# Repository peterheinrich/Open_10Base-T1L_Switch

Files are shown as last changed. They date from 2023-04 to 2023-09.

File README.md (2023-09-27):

# !!! UNTESTED DESIGN STUDY - WORK IN PROGRESS !!!

# Open_10Base-T1L_Switch
Open Hardware 7-Port 10Base-T1L and 1-Port 20/100/1000Base-T Field Switch Design

Schematic: [Open_10Base-T1L_Switch-sch.pdf](Open_10Base-T1L_Switch-sch.pdf)

## Architecture ##
Two 5-port switch ICs (SJA1105Q) form the basis of the design. Daisy chaining the two ICs gives a total of 8 ports.
Seven of these ports are attachted to 10Base-T1L PHYs (ADIN1100), while one port is attached to a 1000Base-T PHY (KSZ9131) as uplink. 

Each of the 10Base-T1L ports offer power over datalines utilizing two 5-Port power management controllers (LTC4296) with SCC support for power delivery negotiation. The design is 24V only and supports PoDL Class 12.

An RP2040 functions as a system controller configuring the switch components.

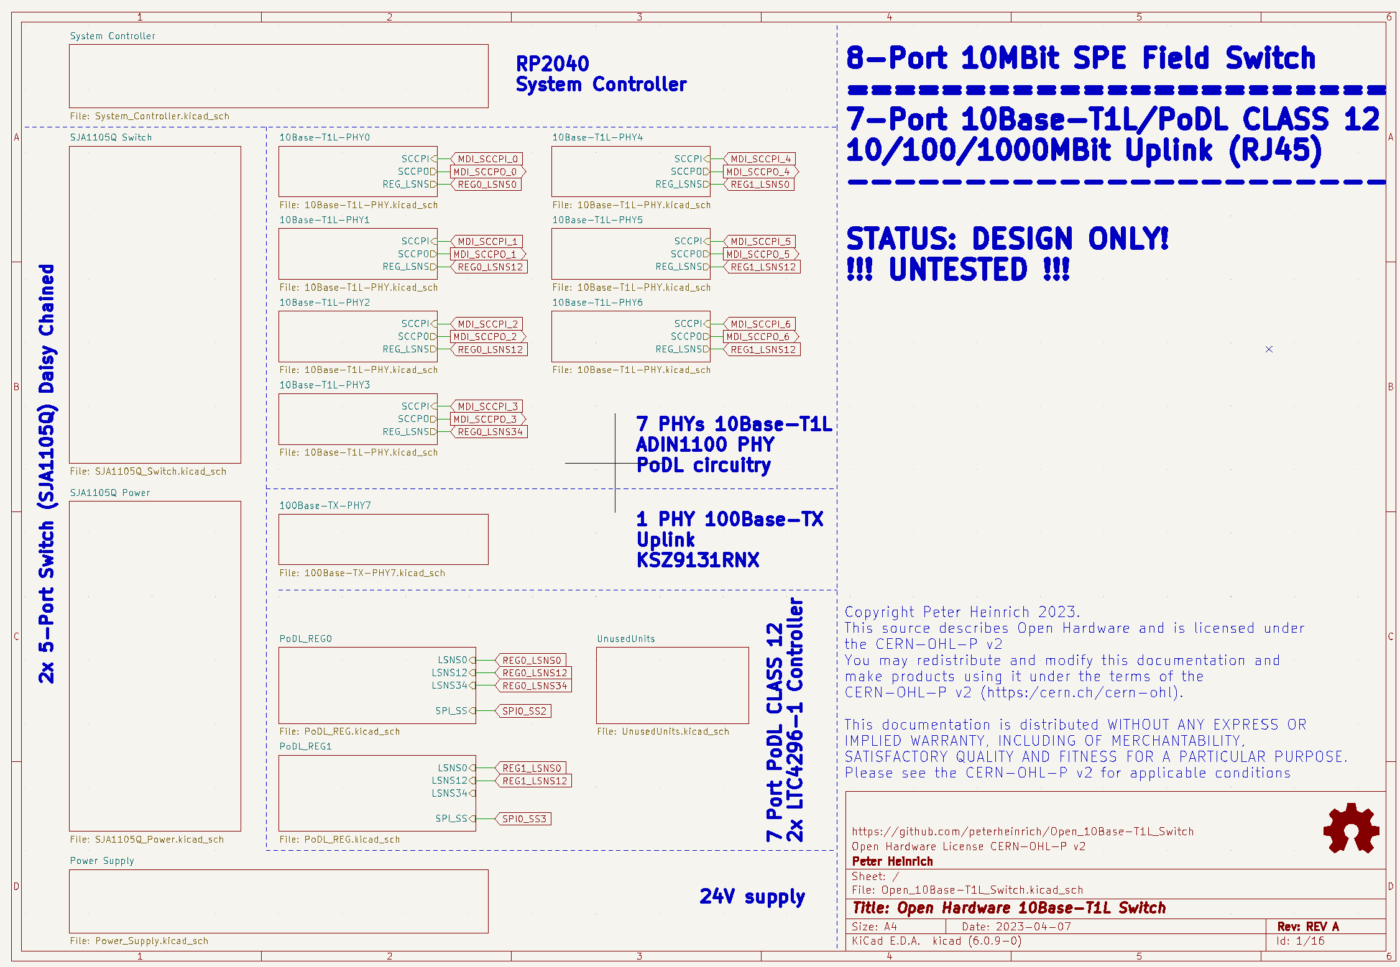
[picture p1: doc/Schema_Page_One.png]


## Current Placement ##
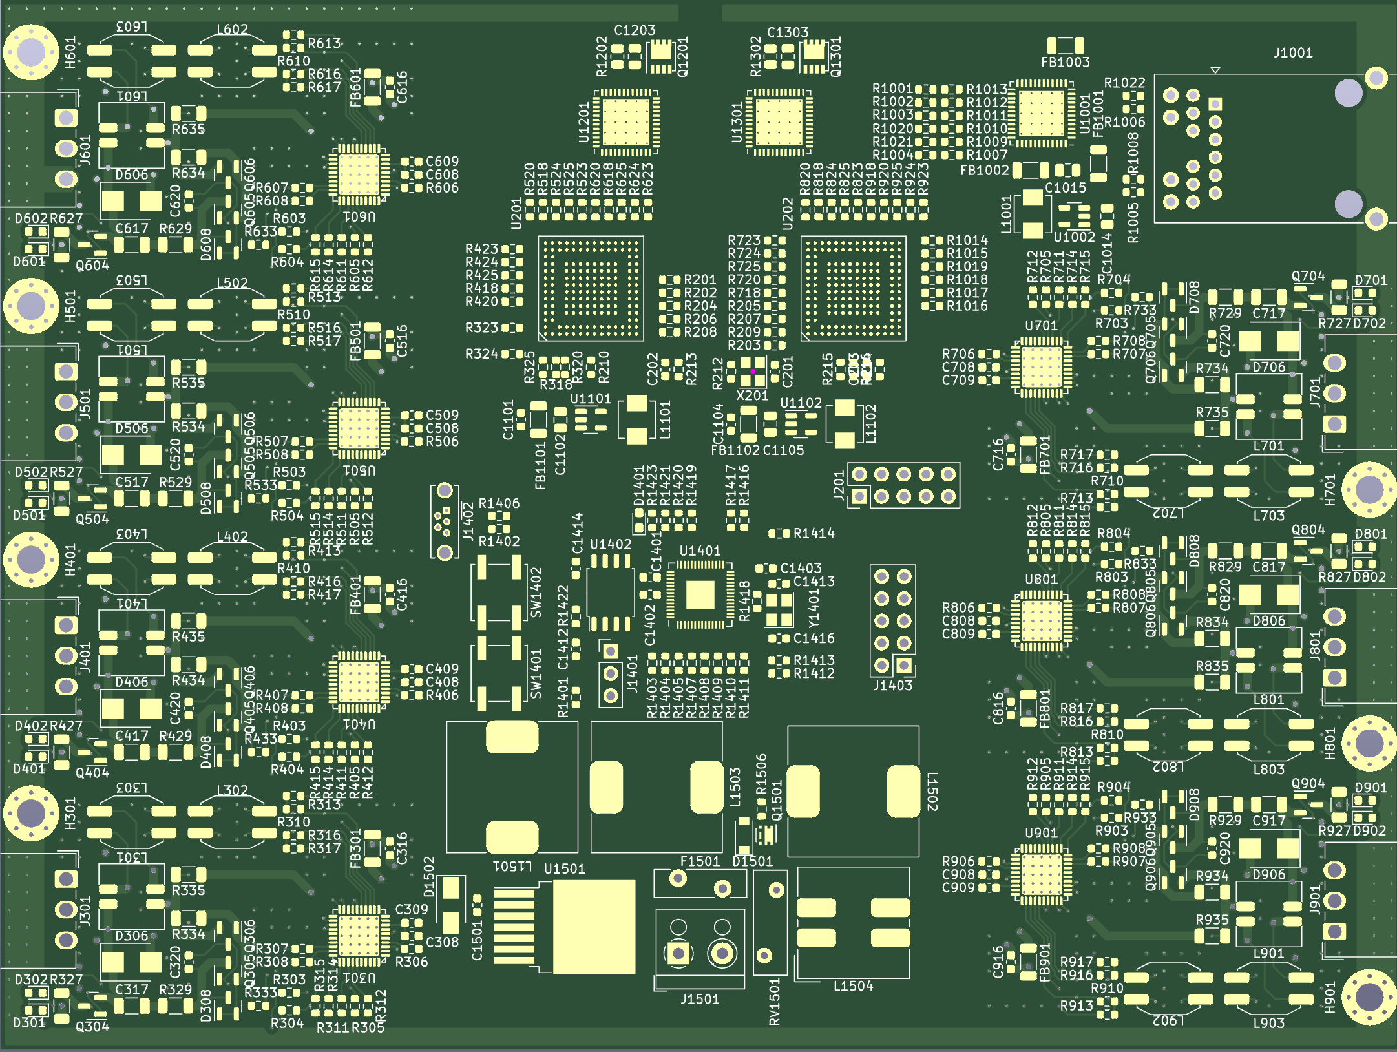
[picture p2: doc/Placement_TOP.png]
Placement Top

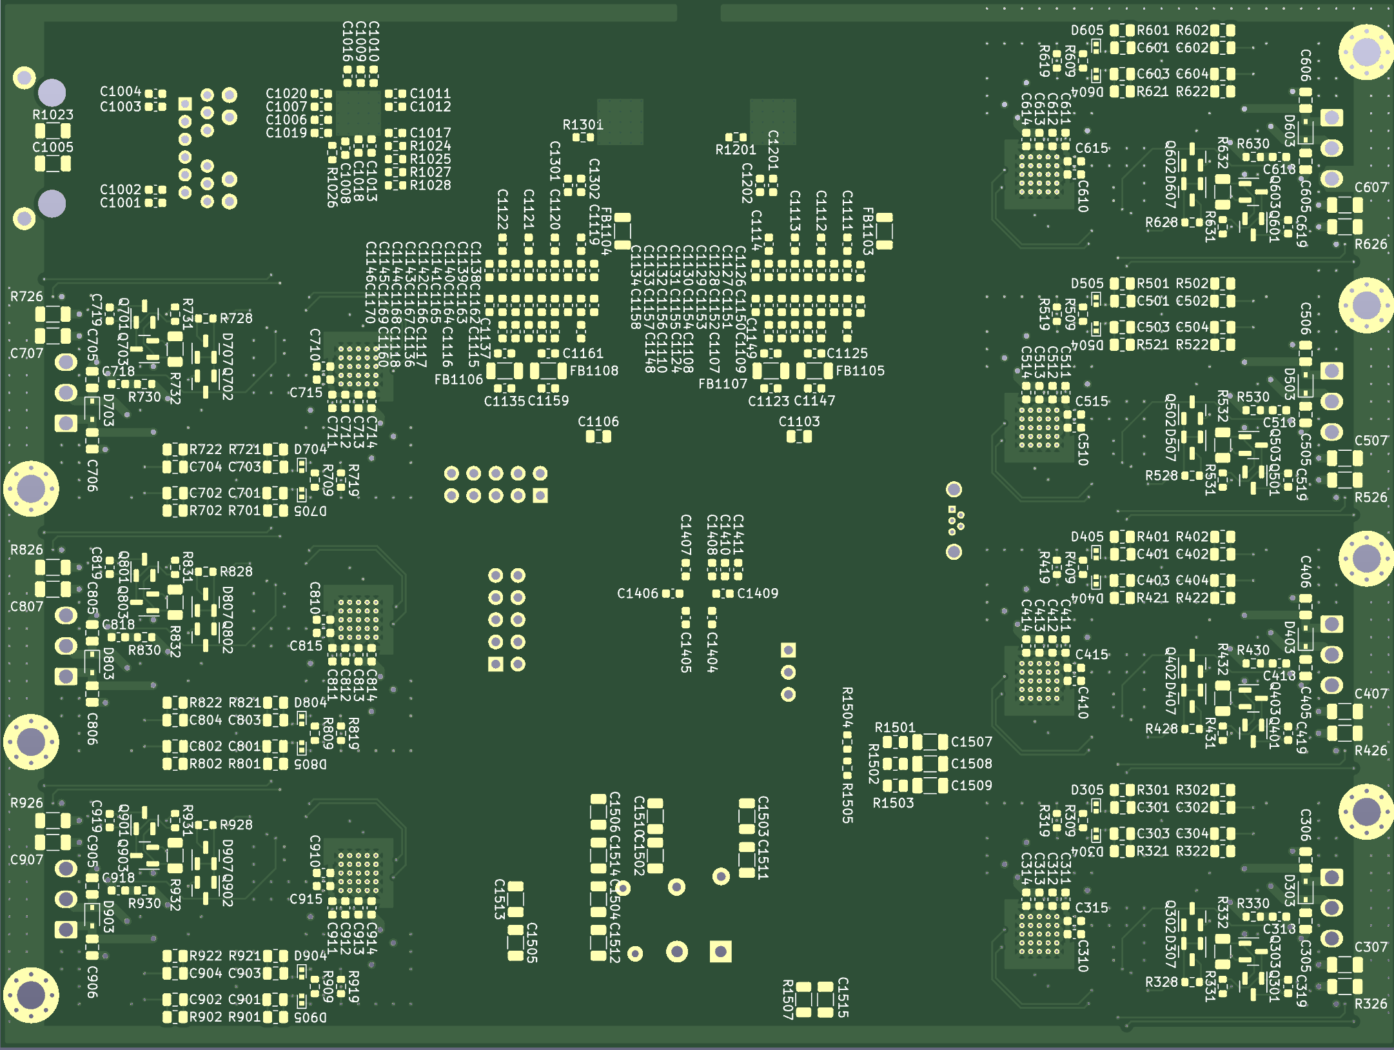
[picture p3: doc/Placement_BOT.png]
Placement Bottom


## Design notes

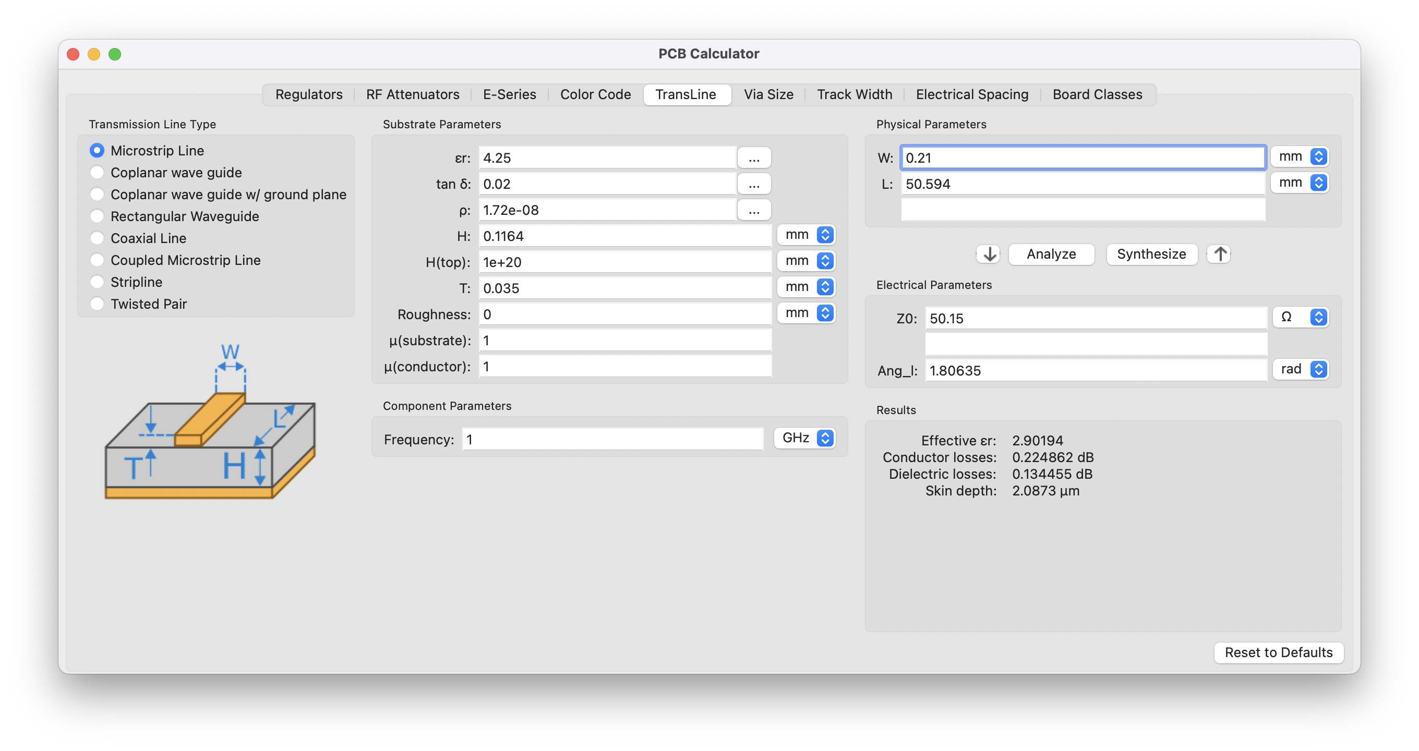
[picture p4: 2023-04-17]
doc/Impedance_Calculation_Top_Bot_Layer.png

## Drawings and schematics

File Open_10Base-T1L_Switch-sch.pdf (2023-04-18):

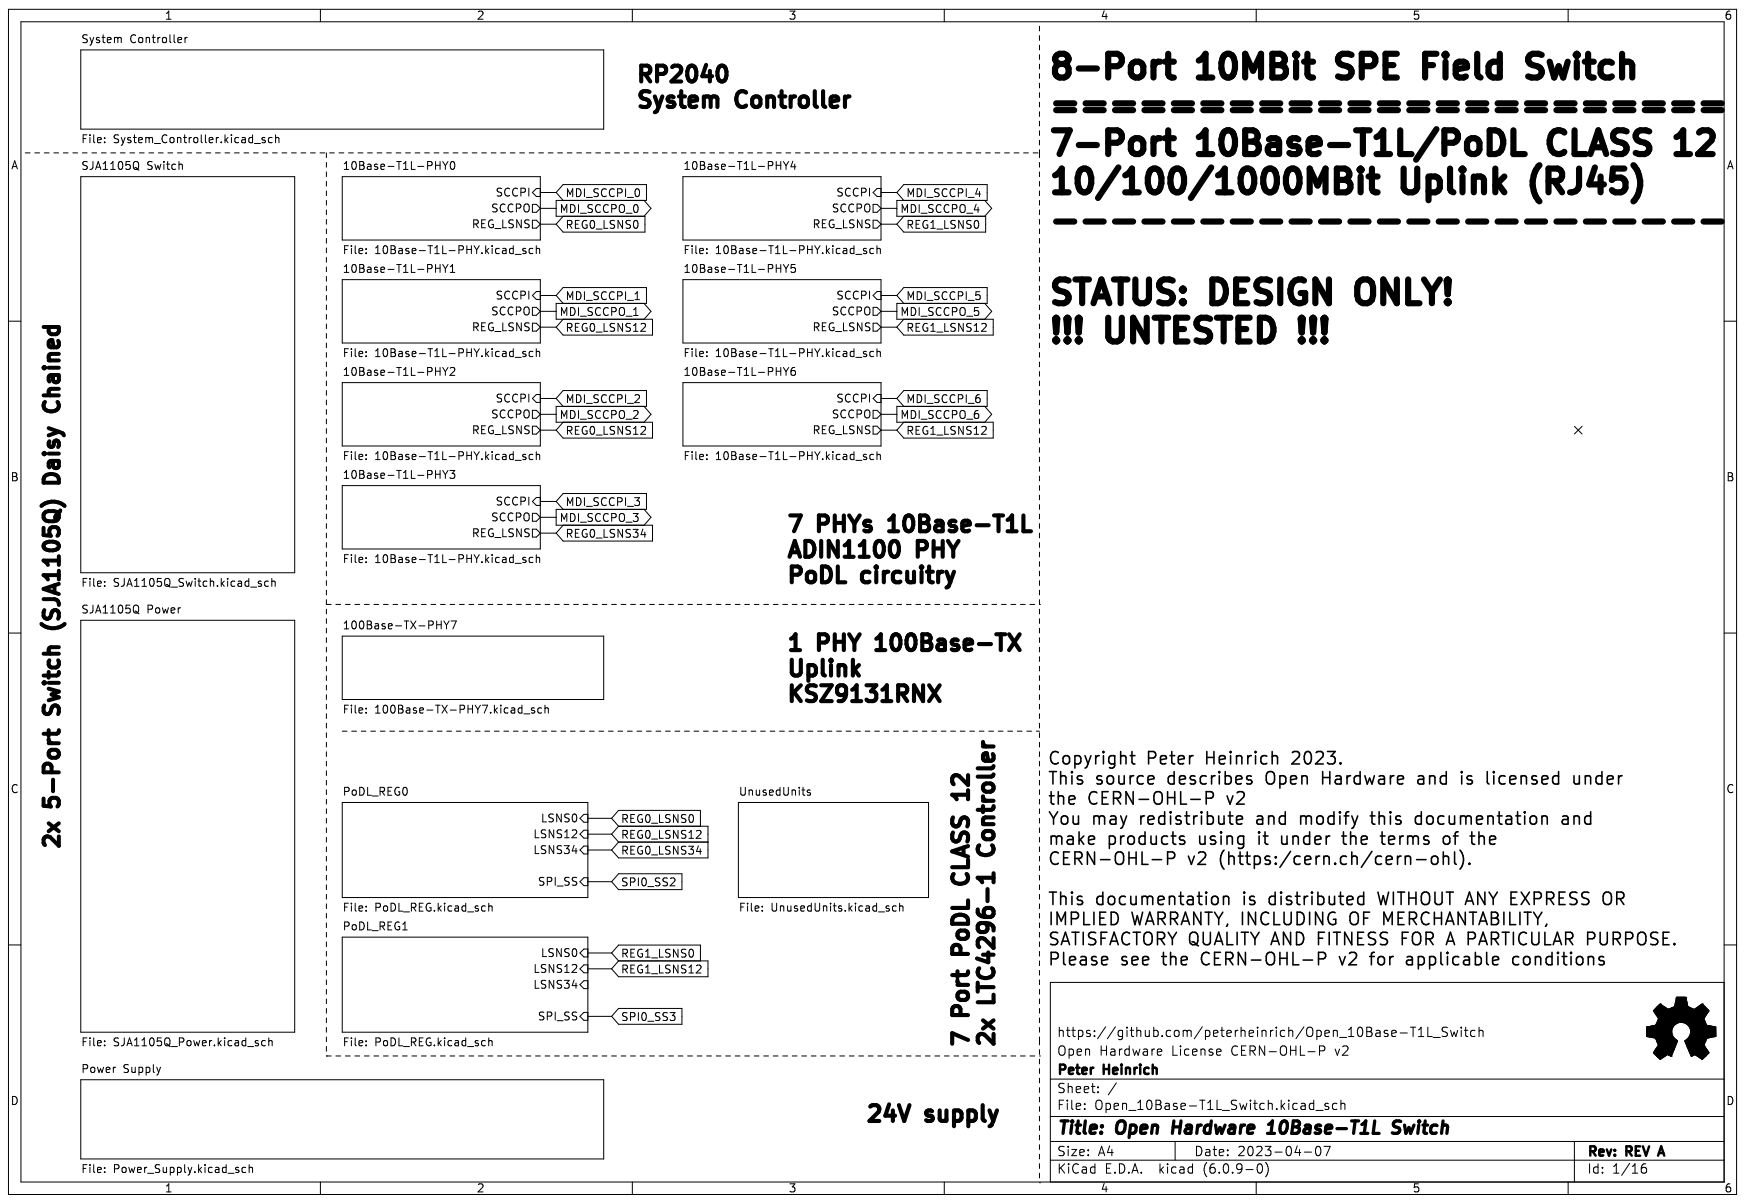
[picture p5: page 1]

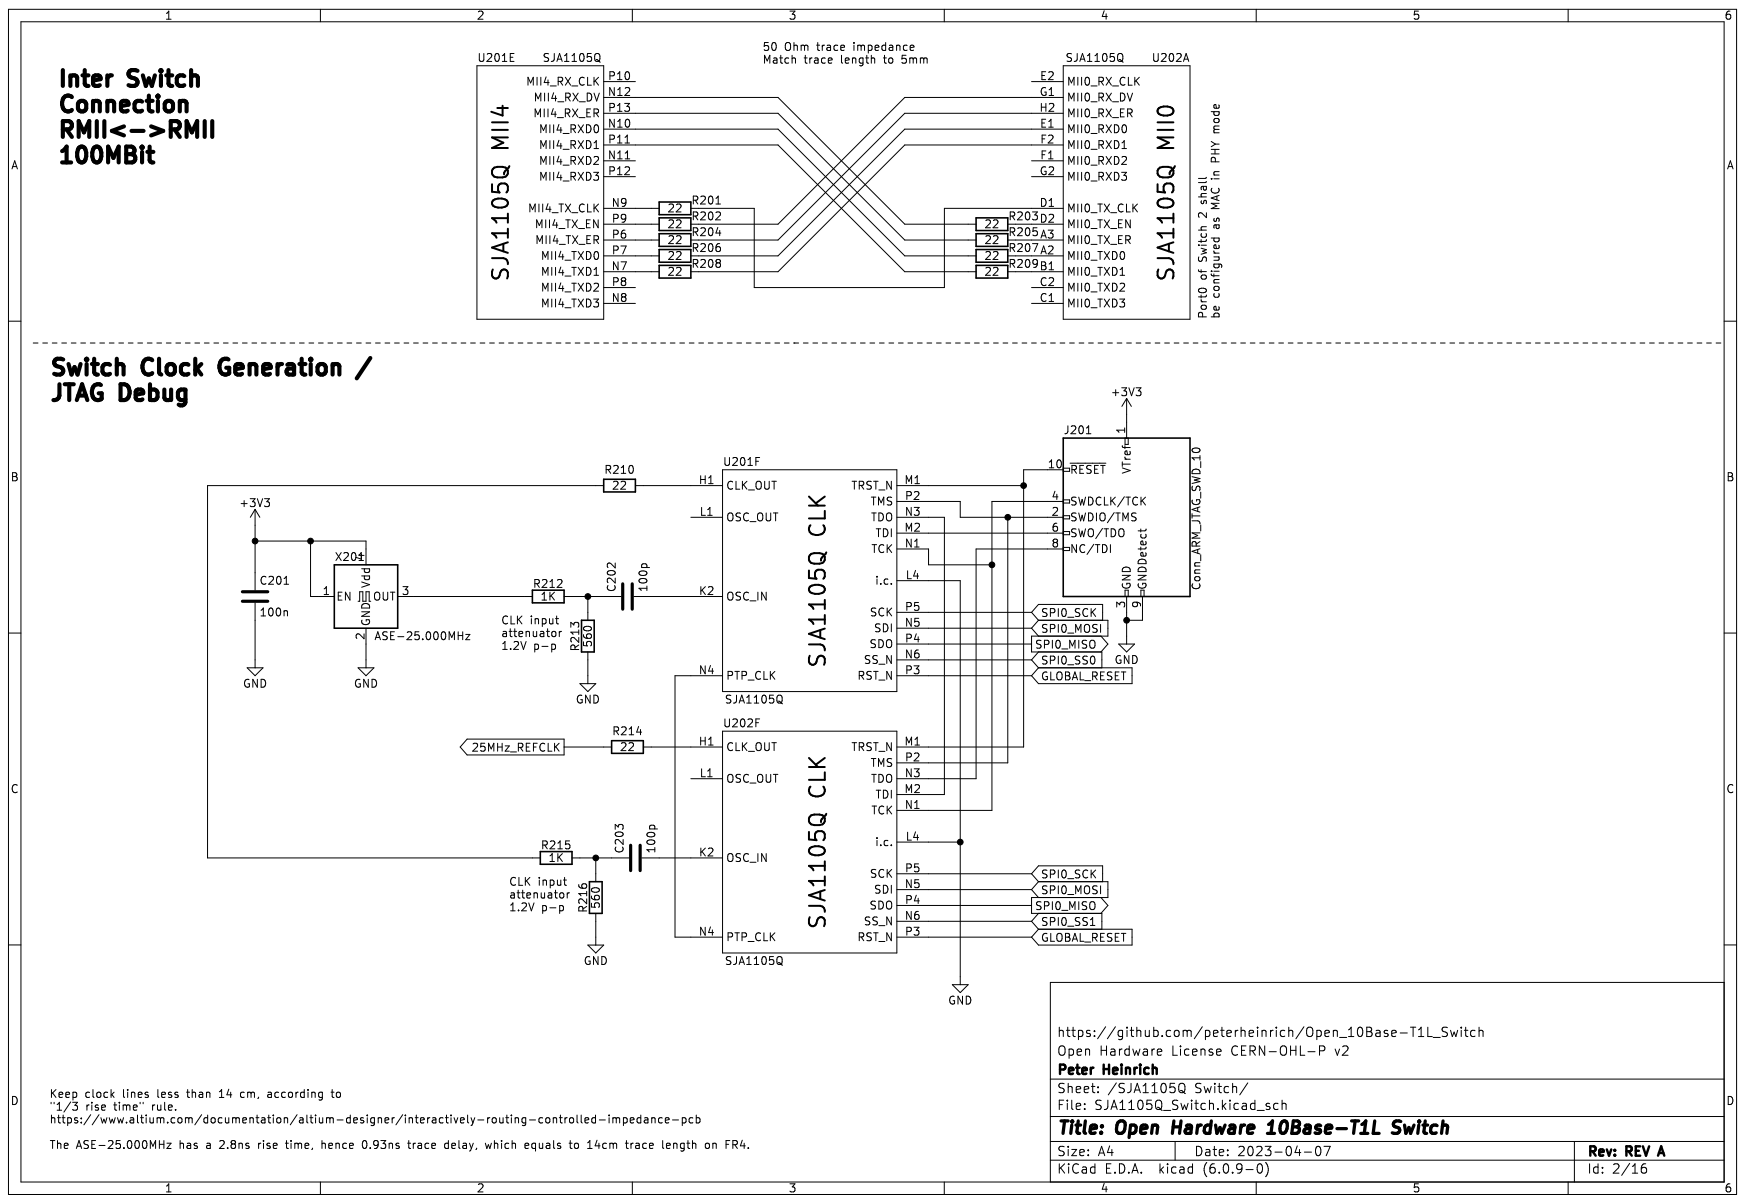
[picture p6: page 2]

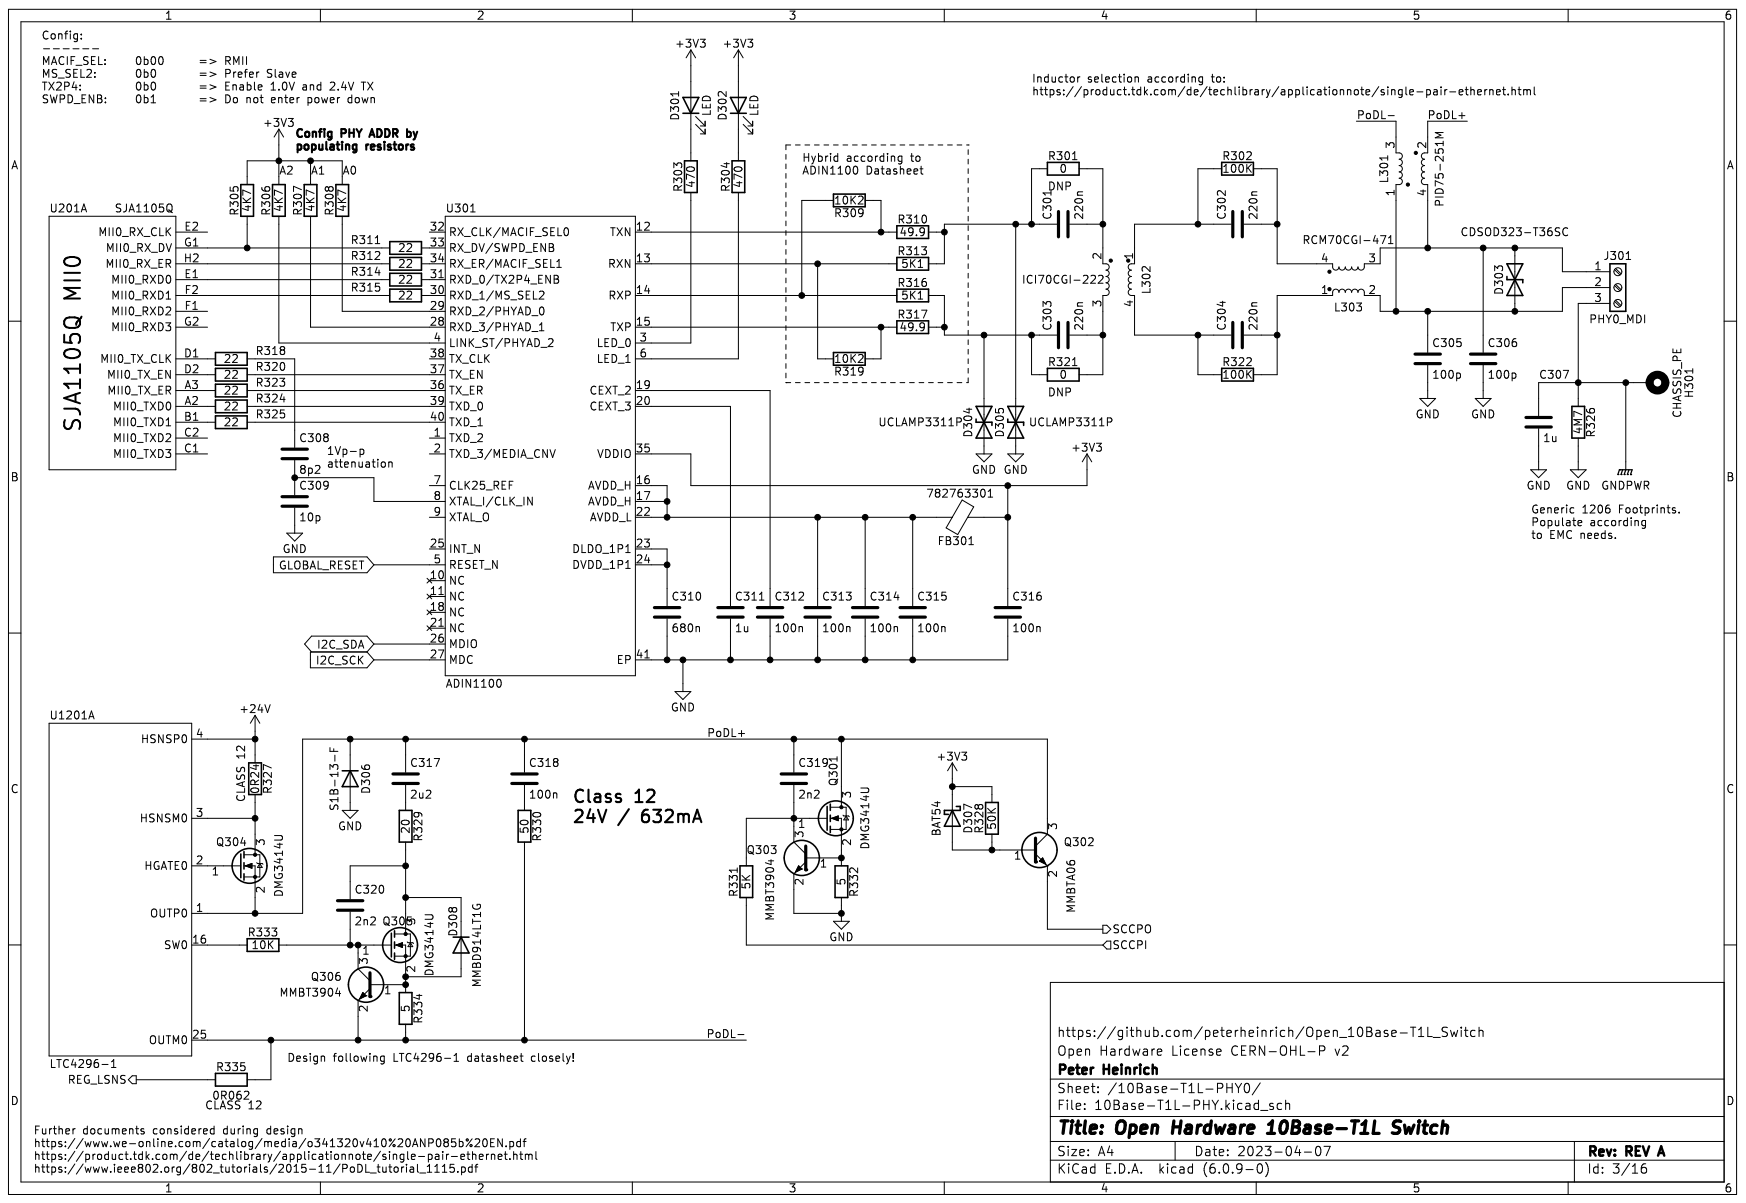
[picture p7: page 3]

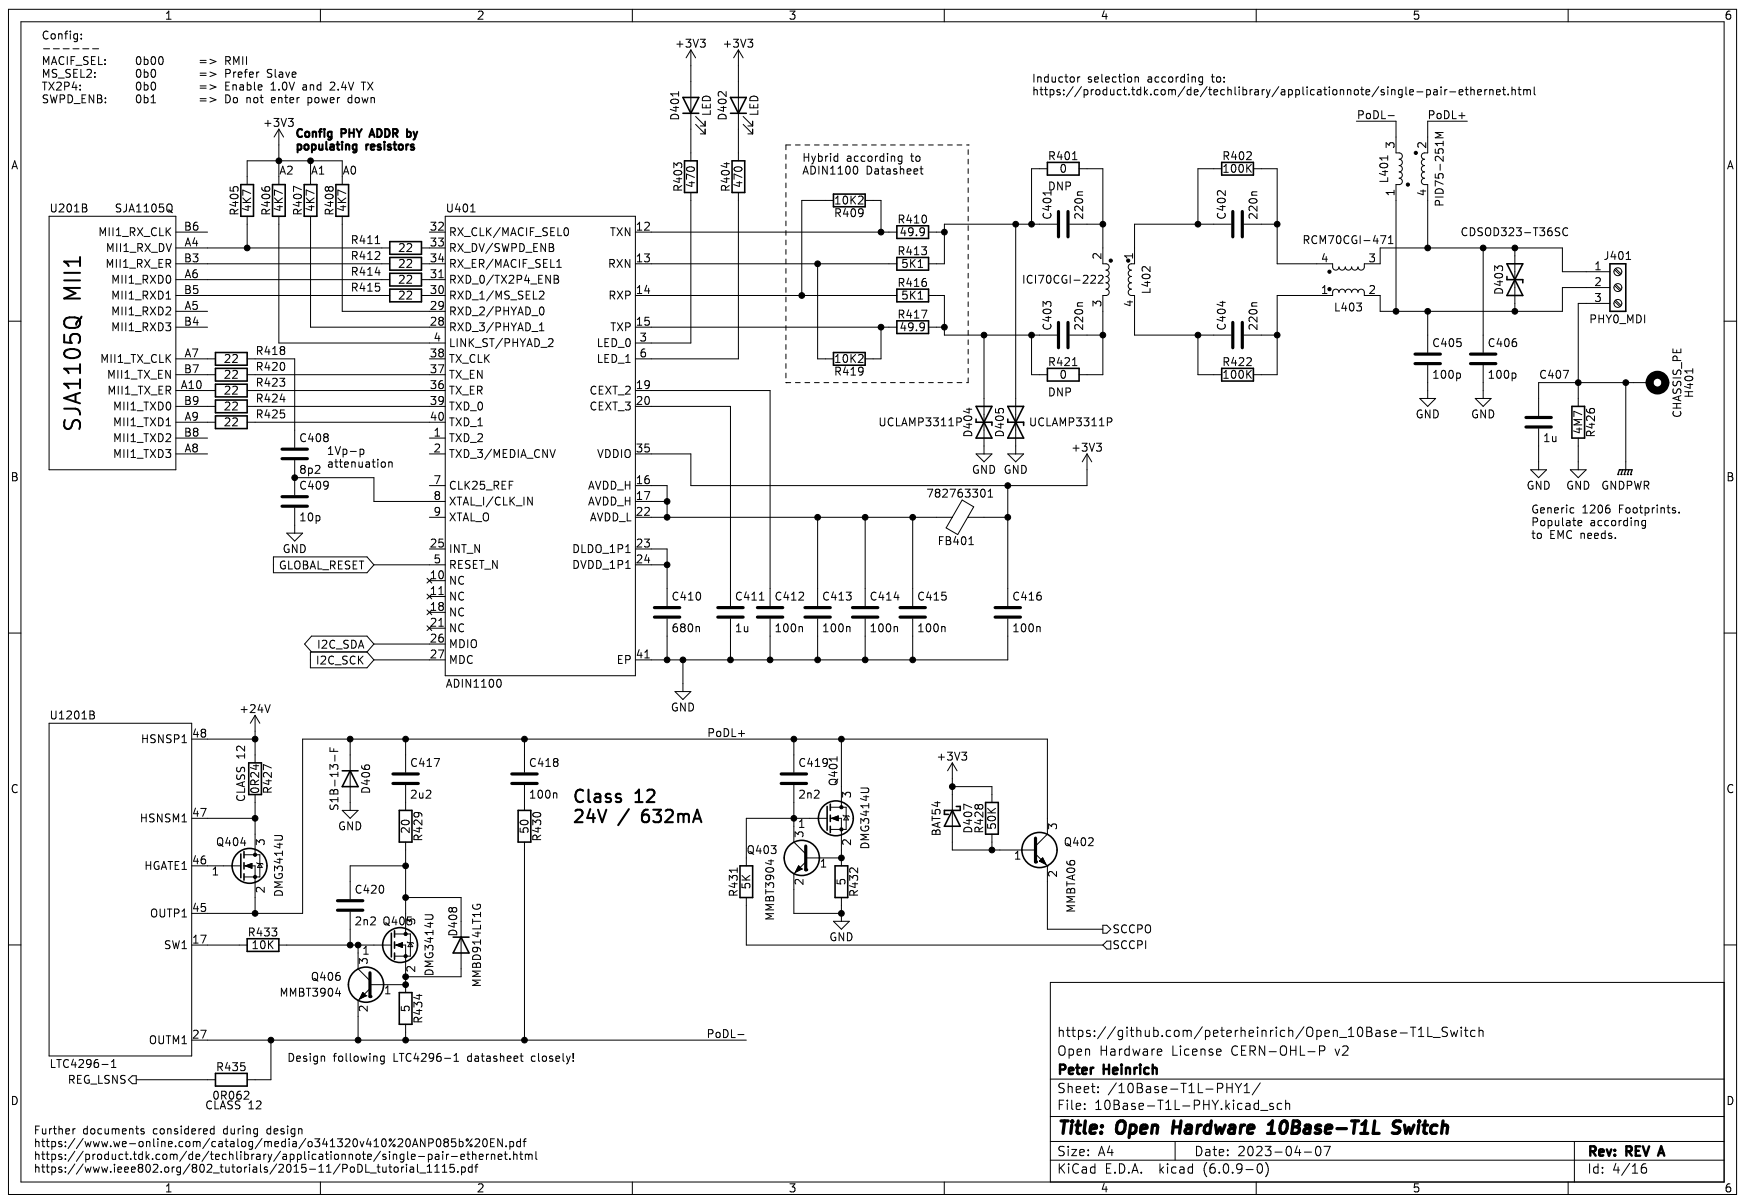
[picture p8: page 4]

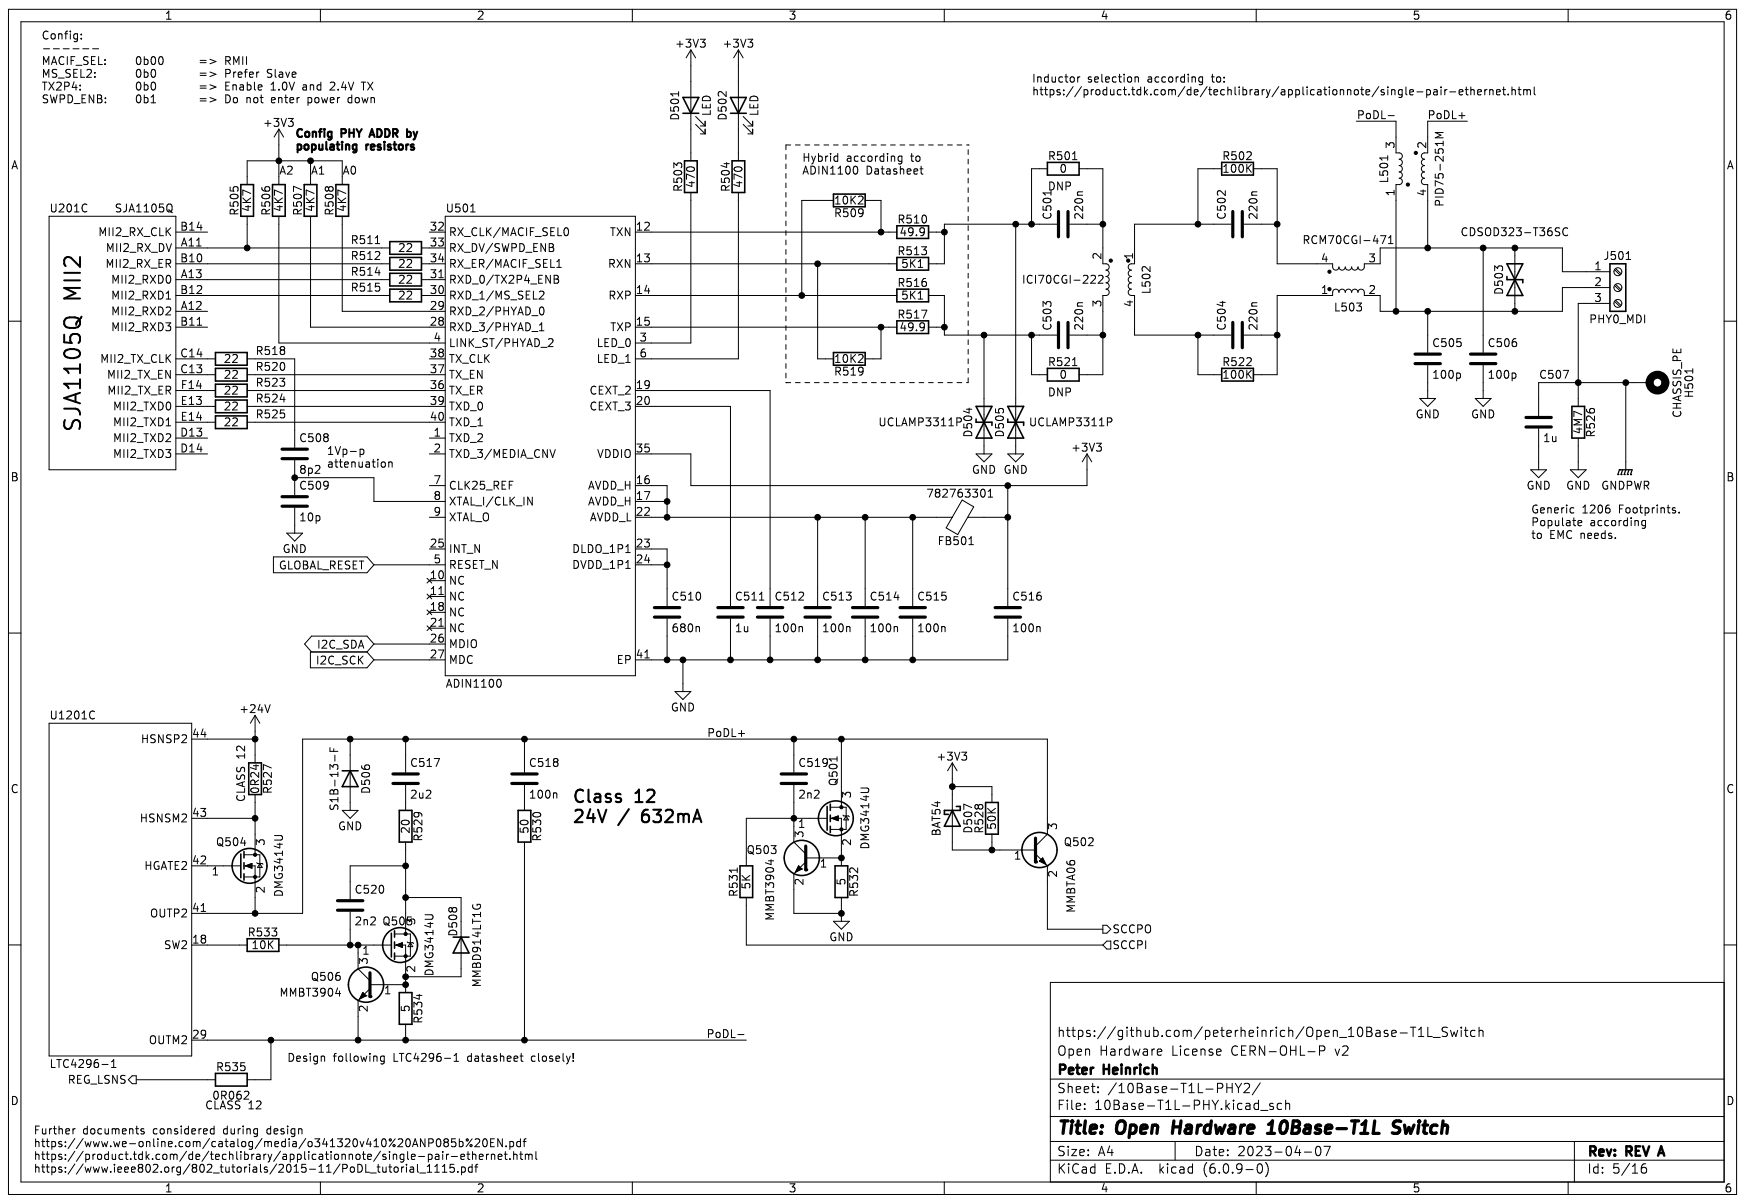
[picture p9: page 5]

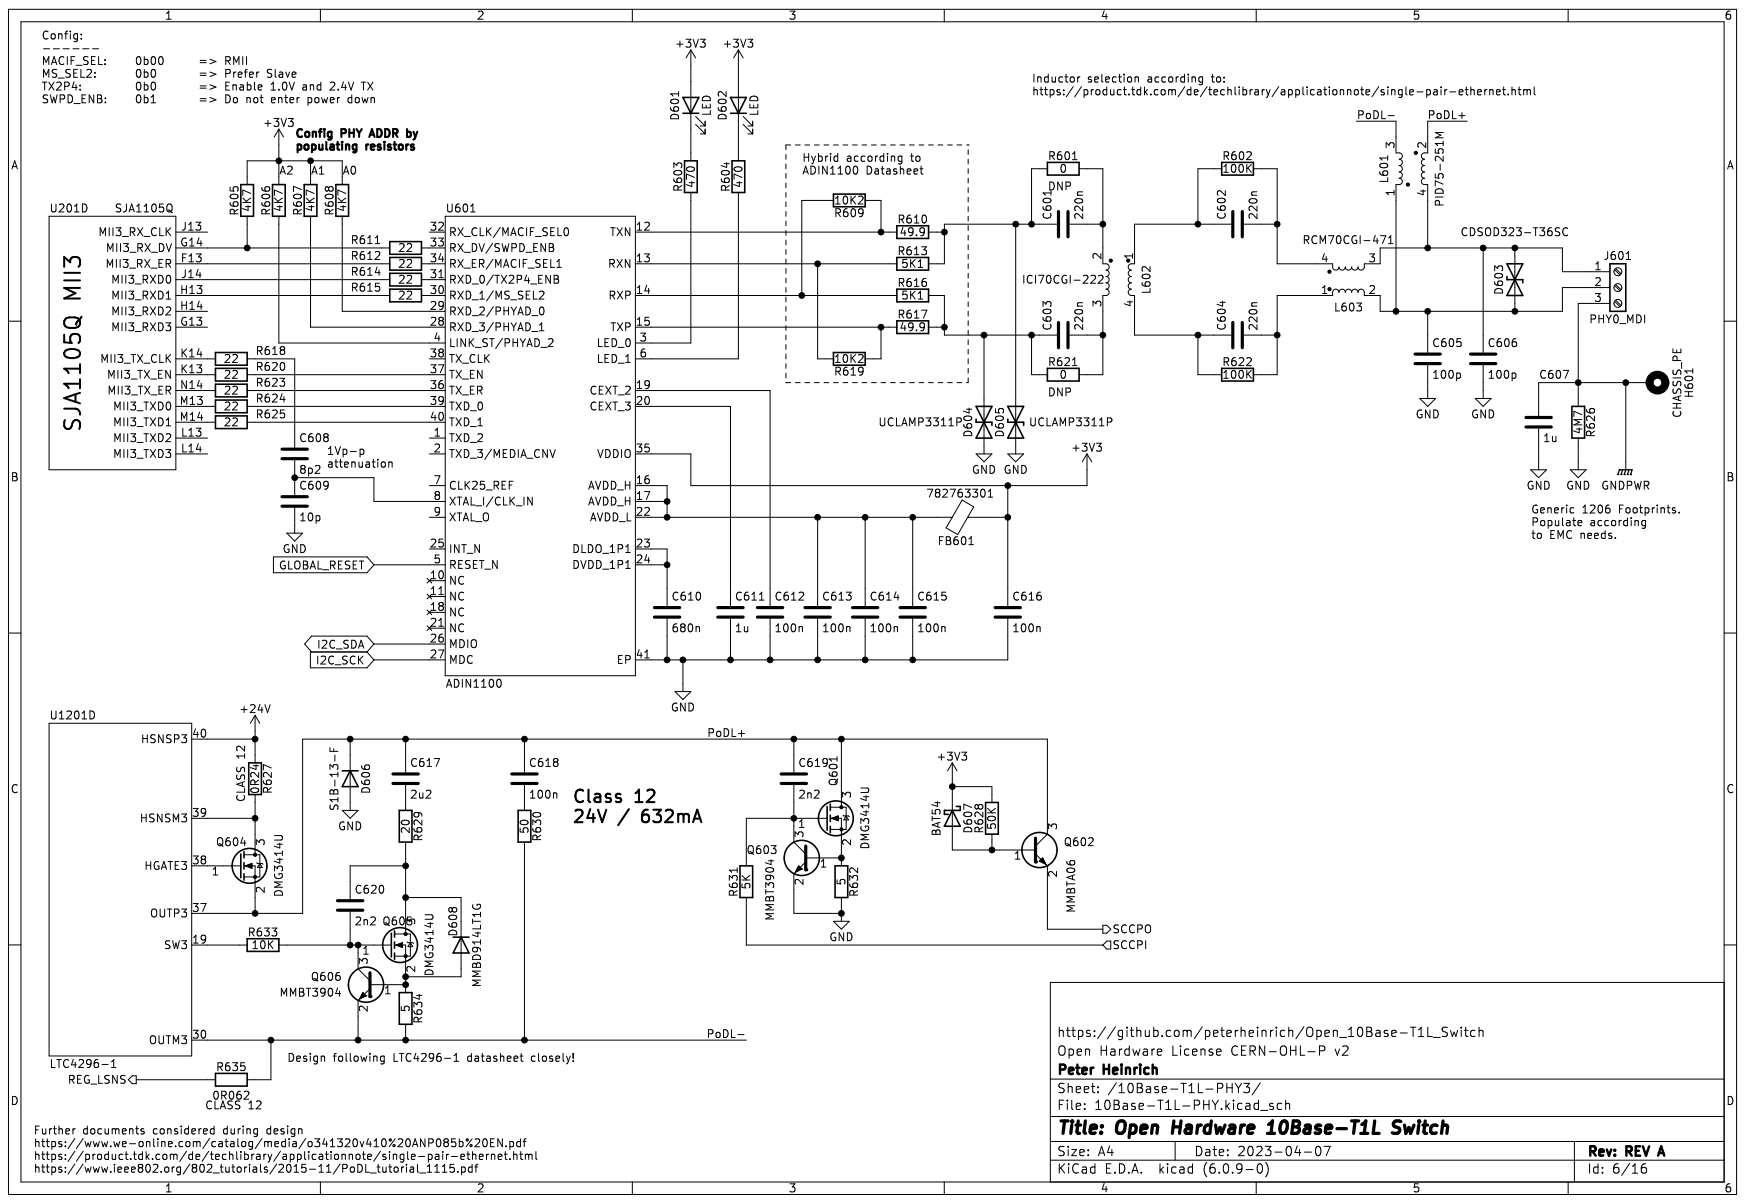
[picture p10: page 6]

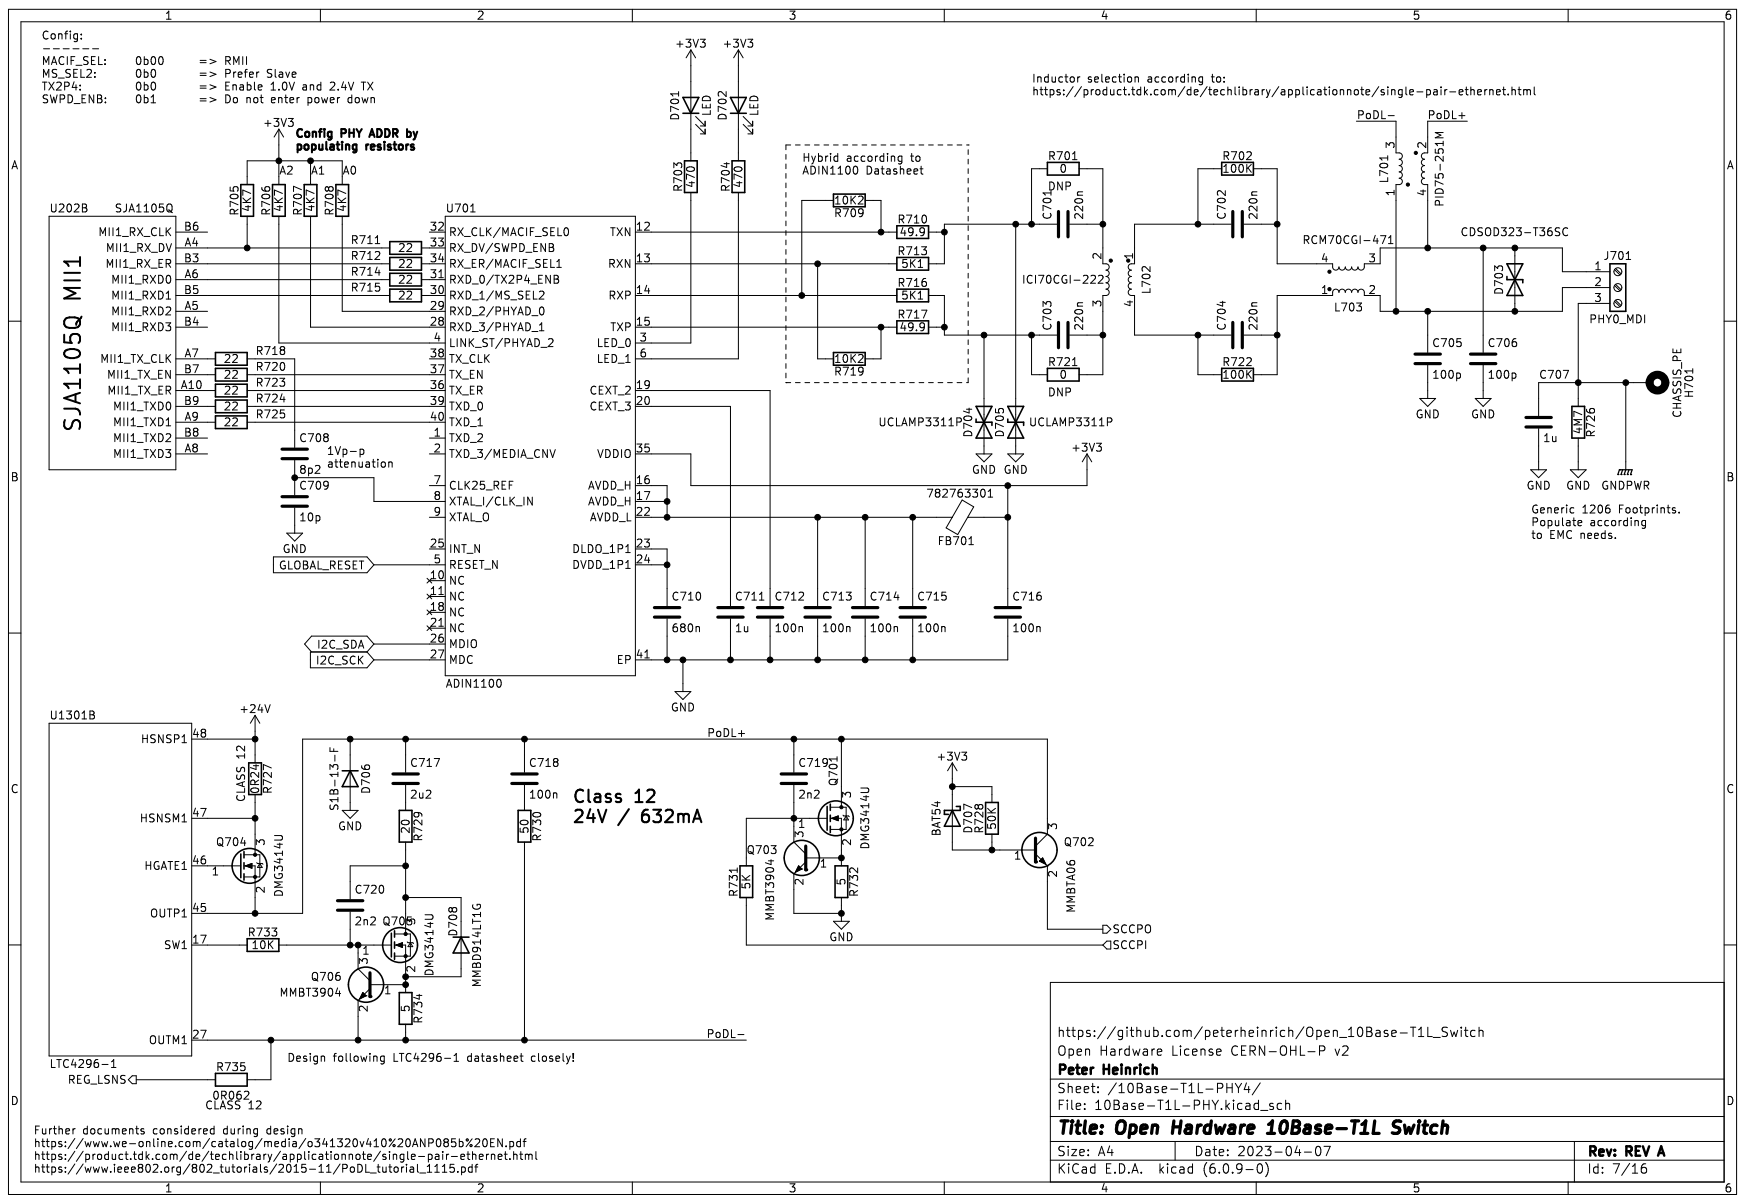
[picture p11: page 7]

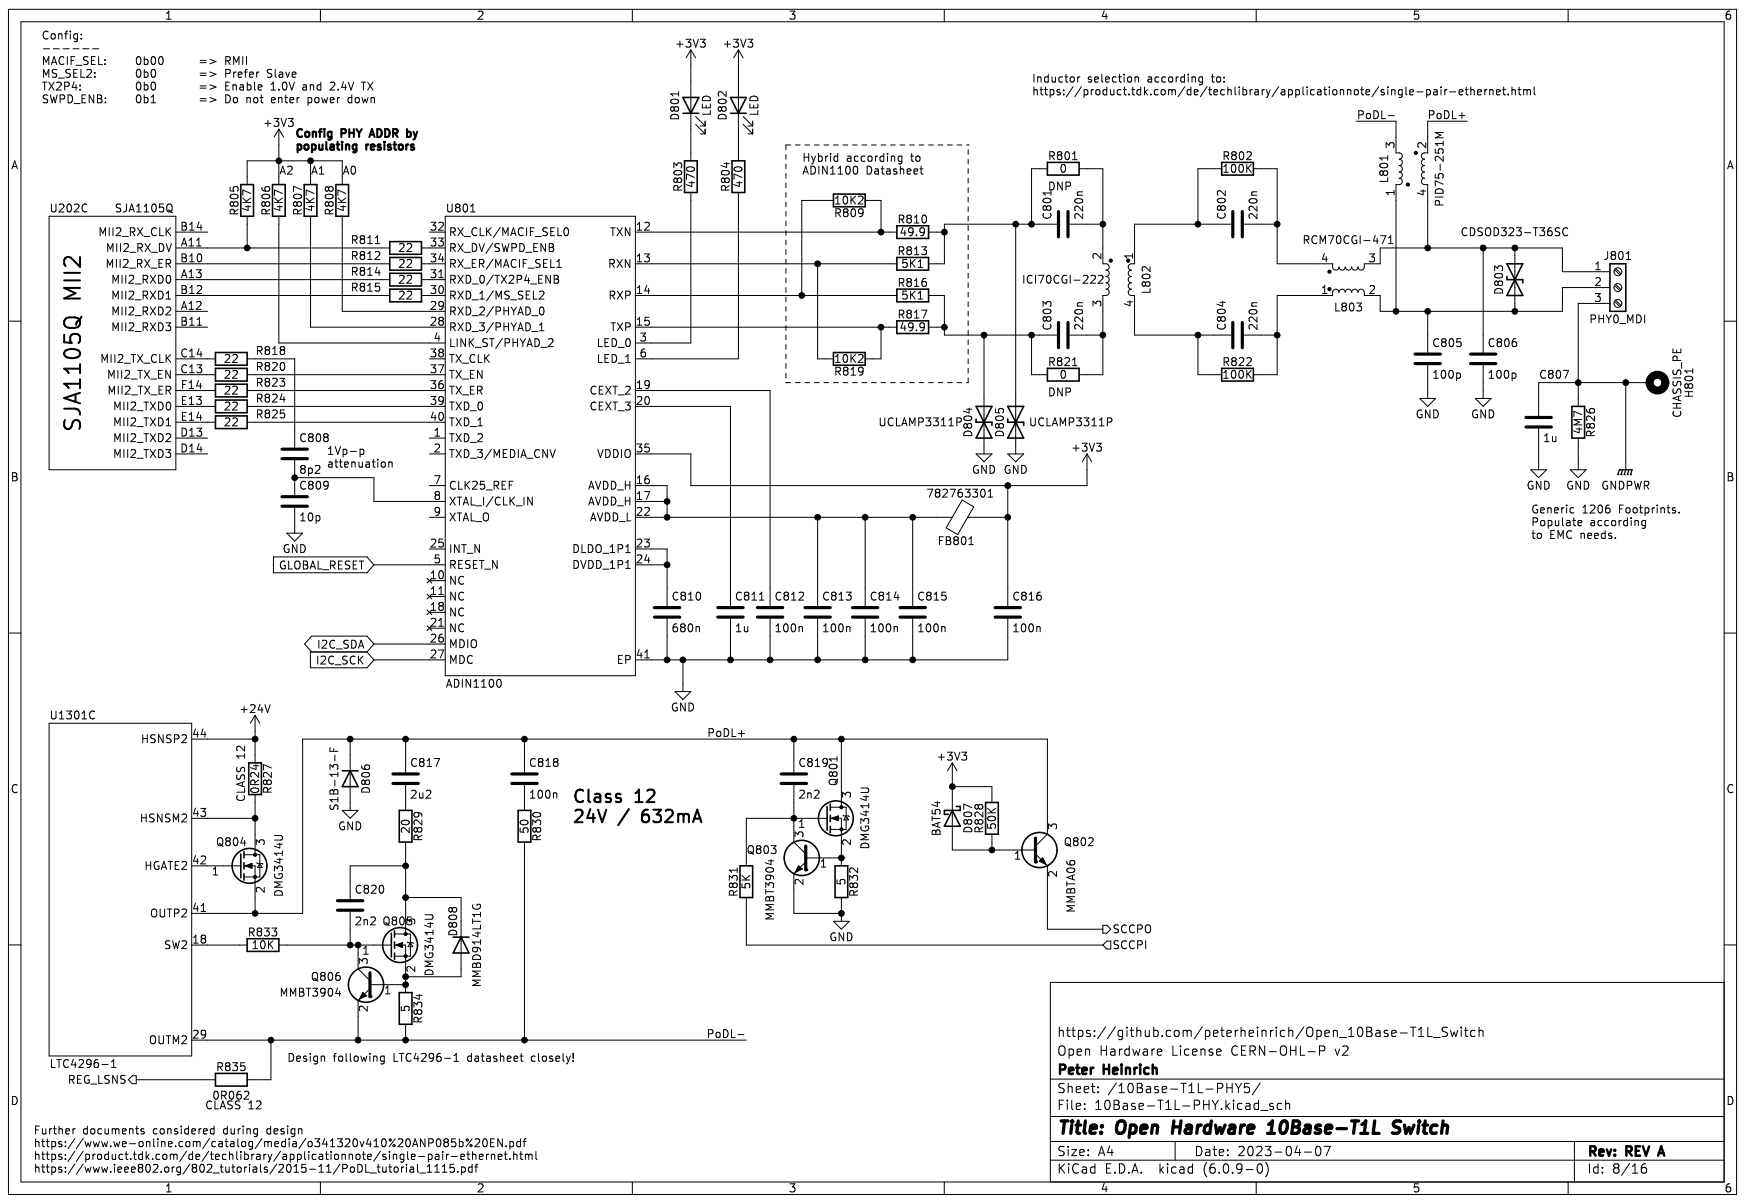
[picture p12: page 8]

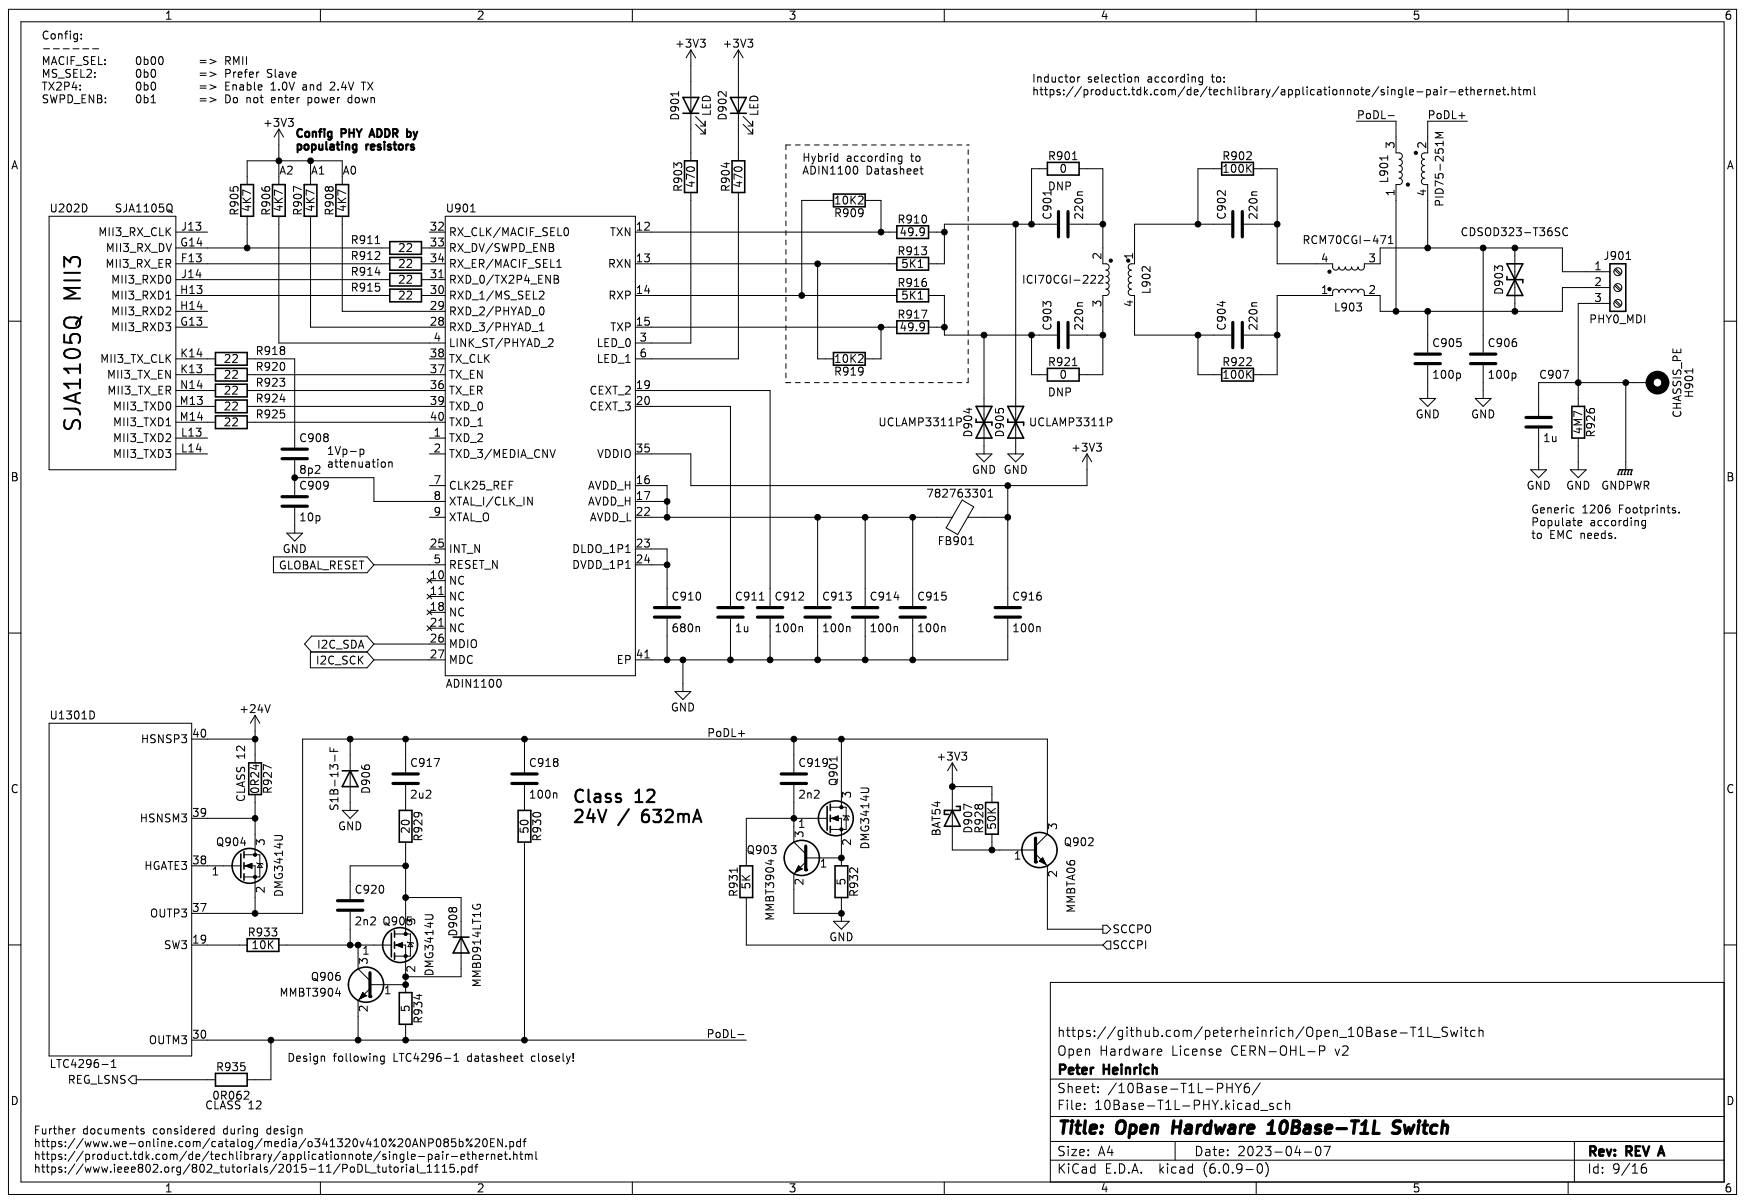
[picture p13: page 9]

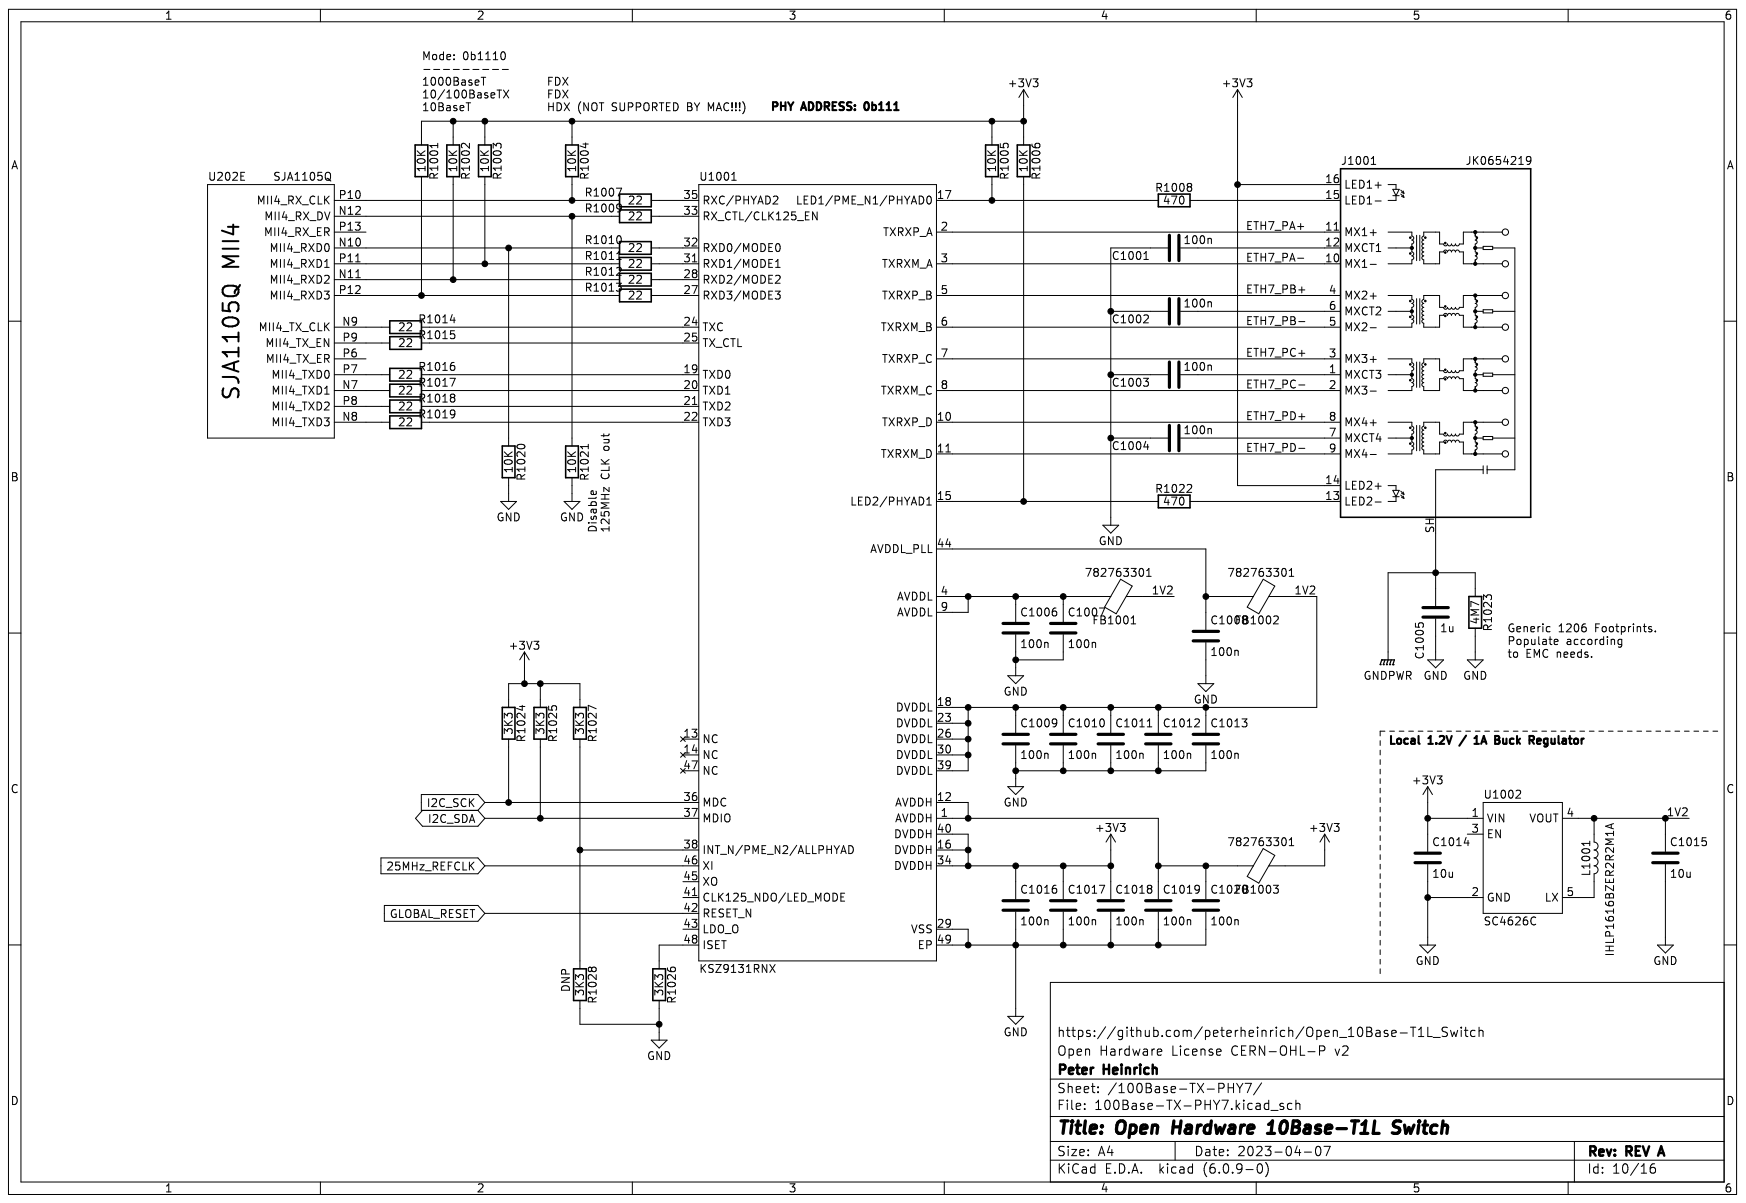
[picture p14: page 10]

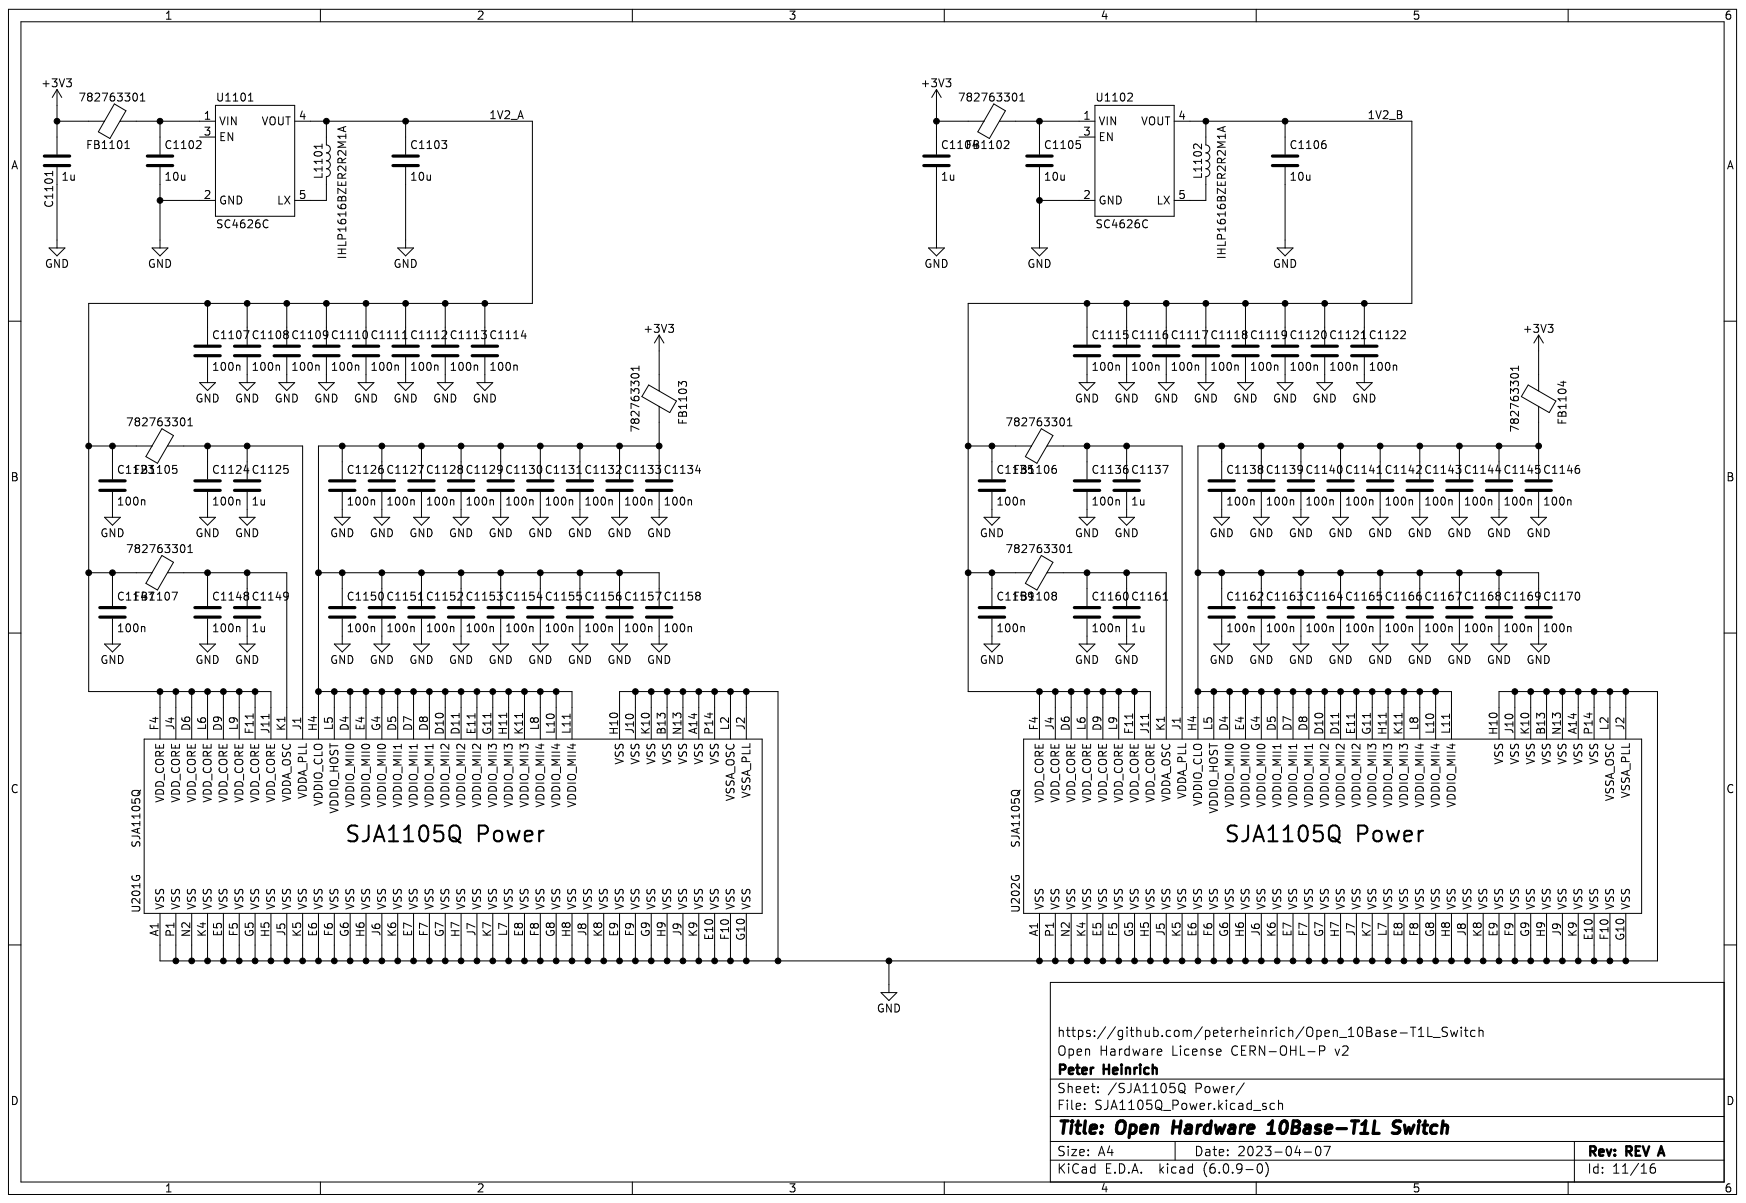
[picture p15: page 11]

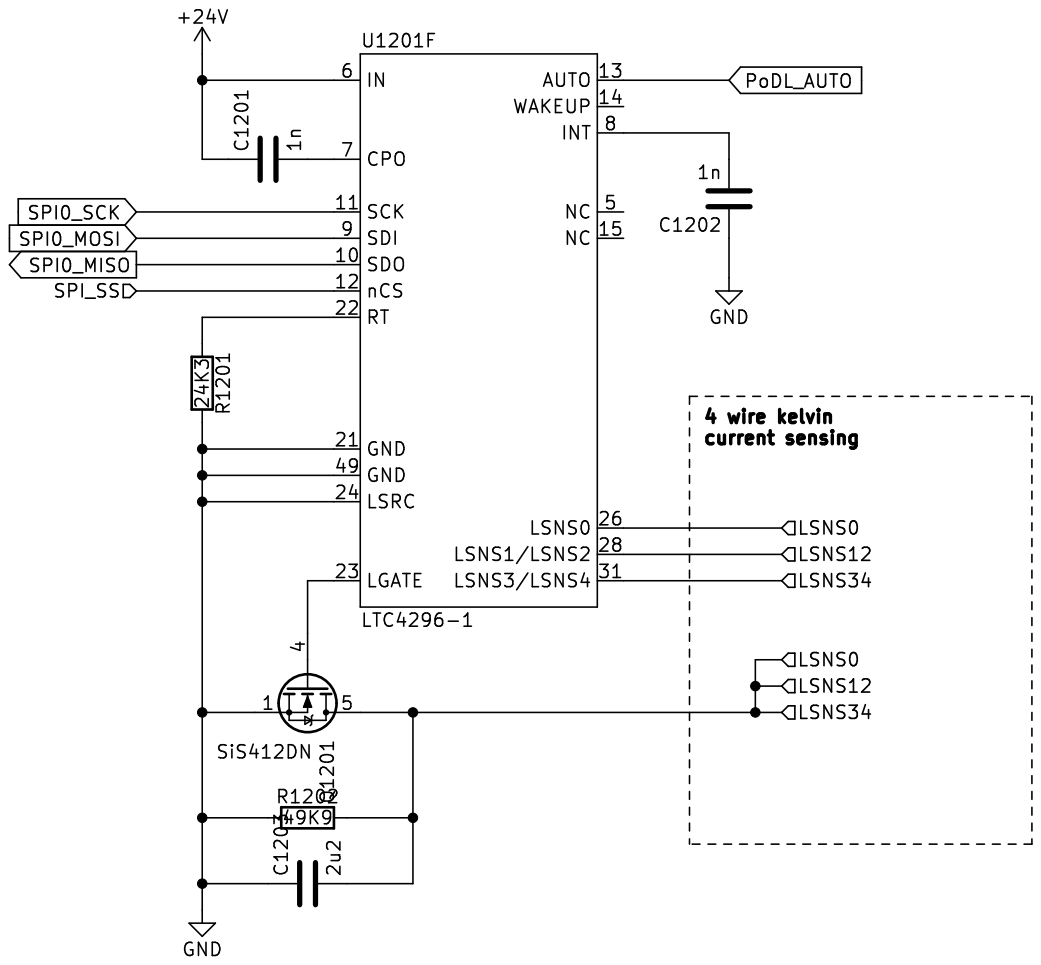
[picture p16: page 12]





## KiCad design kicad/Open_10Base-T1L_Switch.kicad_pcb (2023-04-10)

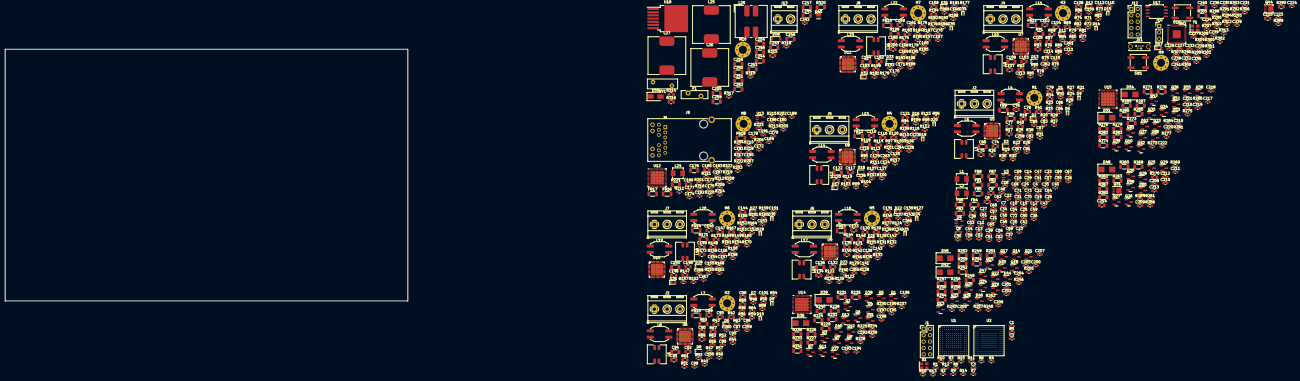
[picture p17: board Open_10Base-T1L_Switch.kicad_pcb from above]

Board: 8 copper layers, 160.0 x 100.0 mm, 789 parts (0 on the bottom side), 588 nets, no tracks yet.

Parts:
C1, C10, C11, C12, C13, C14, C15, C16, C17, C18, C19, C20, C21, C22, C23, C24, C25, C26, C27, C29, C30, C31, C32, C33, C34, C35, C36, C37, C38, C39, C41, C42, C43, C44, C45, C46, C47, C48, C49, C50, C51, C53, C54, C55, C56, C57, C58, C59, C60, C61, C62, C63, C65, C66, C67, C68, C69, C70, C71, C72, C73, C83, C84, C85, C86, C87, C97, C98, C99, C100, C101, C111, C112, C113, C114, C115, C125, C126, C127, C128, C129, C139, C140, C141, C142, C143, C153, C154, C155, C156, C157, C167, C168, C169, C170, C171, C172, C173, C174, C175, C177, C178, C179, C180, C181, C182, C183, C184, C187, C188, C189, C190, C191, C193, C197, C201, C205, C209, C216, C220, C227, C228, C229, C230, C231, C232, C233, C234, C235, C237, C239: 100n; C_0603_1608Metric
C2, C3: 100p; C_0603_1608Metric
C4, C7, C28, C40, C52, C64, C82, C96, C110, C124, C138, C152, C166, C226, C236: 1u; C_0603_1608Metric
C5, C6, C8, C9, C185, C186: 10u; C_0805_2012Metric
C74, C75, C76, C77, C88, C89, C90, C91, C102, C103, C104, C105, C116, C117, C118, C119, C130, C131, C132, C133, C144, C145, C146, C147, C158, C159, C160, C161: 220n; C_0805_2012Metric
C78, C79, C92, C93, C106, C107, C120, C121, C134, C135, C148, C149, C162, C163: 10n; C_0805_2012Metric
C80, C94, C108, C122, C136, C150, C164, C176, C240, C256: 1u; C_1206_3216Metric
C81, C95, C109, C123, C137, C151, C165: 680n; C_0603_1608Metric
C192, C196, C200, C204, C208, C215, C219: 2u2; C_0603_1608Metric
C194, C195, C198, C199, C202, C203, C206, C207, C210, C211, C217, C218, C221, C222: 2n2; C_0603_1608Metric
C212, C213, C223, C224: 1n; C_0603_1608Metric
C214, C225: 2u2; C_0805_2012Metric
C238, C241, C258, C260, C262, C264, C266, C268, C270: 10p; C_0603_1608Metric
C242: 10n; C_0603_1608Metric
C243, C244, C245, C246, C247, C251, C252, C253, C254, C255: 22u; C_1206_3216Metric
C248, C249, C250: 47u; C_1206_3216Metric
C257, C259, C261, C263, C265, C267, C269: 8p2; C_0603_1608Metric
D1, D2, D6, D7, D11, D12, D16, D17, D21, D22, D26, D27, D31, D32: LED; LED_0603_1608Metric
D3, D8, D13, D18, D23, D28, D33: CDSOD323-T36SC; D_SOD-323
D4, D5, D9, D10, D14, D15, D19, D20, D24, D25, D29, D30, D34, D35: UCLAMP3311P; SLP1006P2
D36, D39, D42, D45, D48, D51, D54: S1B-13-F; D_SMB
D37, D40, D43, D46, D49, D52, D55: BAT54; SOT-23-DIODE
D38, D41, D44, D47, D50, D53, D56: MMBD914LT1G; SOT-23-DIODE
D57: LED; LED_0603_1608Metric_Pad1.05x0.95mm_HandSolder
D58: BZT52C10; D_SOD-123
D59: SDT5A60SA-13; D_SMA
F1: RUEF500; Fuse_Bourns_MF-RG500
FB1, FB2, FB3, FB4, FB5, FB6, FB7, FB8, FB16, FB17, FB18: 782763301; L_1206_3216Metric
FB9, FB10, FB11, FB12, FB13, FB14, FB15: FerriteBead; L_1206_3216Metric
H1, H2, H3, H4, H5, H6, H7, H8, H9, H10: CHASSIS_PE; MountingHole_3.2mm_M3_Pad_Via
J1, J12: Conn_ARM_JTAG_SWD_10; PinHeader_2x05_P2.54mm_Vertical
J2: PHY0_MDI; TerminalBlock_RND_205-00288_1x03_P5.08mm_Horizontal
J3: PHY1_MDI; TerminalBlock_RND_205-00288_1x03_P5.08mm_Horizontal
J4: PHY2_MDI; TerminalBlock_RND_205-00288_1x03_P5.08mm_Horizontal
J5: PHY3_MDI; TerminalBlock_RND_205-00288_1x03_P5.08mm_Horizontal
J6: PHY4_MDI; TerminalBlock_RND_205-00288_1x03_P5.08mm_Horizontal
J7: PHY5_MDI; TerminalBlock_RND_205-00288_1x03_P5.08mm_Horizontal
J8: PHY6_MDI; TerminalBlock_RND_205-00288_1x03_P5.08mm_Horizontal
J9: JK0654219; RJ45_Pulse_JK0654219NL_Horizontal
J10: CONSOLE; PinHeader_1x03_P2.54mm_Vertical
J11: USB_B_Micro; USB_Micro-B_Wuerth_614105150721_Vertical_CircularHoles
J13: PWR IN; TerminalBlock_RND_205-00287_1x02_P5.08mm_Horizontal
L1, L2, L24: IHLP1616BZER2R2M1A; L_Vishay_IHLP-1616
L3, L6, L9, L12, L15, L18, L21: PID75-251M
L4, L7, L10, L13, L16, L19, L22: ICI70CGI-222; ICI70CGI
L5, L8, L11, L14, L17, L20, L23: RCM70CGI-471; ICI70CGI
L25, L26, L27: MSS1583-103MED; MSS1583
L28: B82477D6103M603; L_Bourns_SRF1260
Q1, Q4, Q5, Q7, Q10, Q11, Q13, Q16, Q17, Q19, Q22, Q23, Q25, Q28, Q29, Q32, Q35, Q36, Q38, Q41, Q42: DMG3414U; SOT-23
Q2, Q8, Q14, Q20, Q26, Q33, Q39: MMBTA06; SOT-23
Q3, Q6, Q9, Q12, Q15, Q18, Q21, Q24, Q27, Q30, Q34, Q37, Q40, Q43: MMBT3904; SOT-23
Q31, Q44: SiS412DN; Vishay_PowerPAK_1212-8_Single
Q45: SiA449DJ; Vishay_PowerPAK_SC70-6L_Single
R1, R2, R3, R4, R5, R6, R7, R8, R9, R10, R11, R14, R24, R25, R27, R28, R31, R33, R36, R37, R38, R50, R51, R53, R54, R57, R59, R62, R63, R64, R76, R77, R79, R80, R83, R85, R88, R89, R90, R103, R104, R106, R107, R110, R112, R115, R116, R117, R129, R130, R132, R133, R136, R138, R141, R142, R143, R156, R157, R159, R160, R163, R165, R168, R169, R170, R183, R184, R186, R187, R190, R192, R195, R196, R197, R207, R208, R209, R210, R211, R212, R213, R214, R215, R216, R217, R218: 22; R_0603_1608Metric
R12, R15, R99, R100, R308: 1K; R_0603_1608Metric
R13, R16: 560; R_0603_1608Metric
R17, R34, R42, R60, R68, R86, R94, R113, R121, R139, R147, R166, R174, R193: 0; R_0805_2012Metric
R18, R35, R43, R61, R69, R87, R95, R114, R122, R140, R148, R167, R175, R194: 100K; R_0805_2012Metric
R19, R20, R44, R45, R70, R71, R96, R97, R123, R124, R149, R150, R176, R177, R313, R321, R322: 470; R_0603_1608Metric
R21, R46, R47, R72, R73, R125, R126, R151, R152, R153, R178, R179, R180, R317: 4K7; R_0603_1608Metric
R22, R32, R48, R58, R74, R84, R101, R111, R127, R137, R154, R164, R181, R191: 10K2; R_0603_1608Metric
R23, R30, R49, R56, R75, R82, R102, R109, R128, R135, R155, R162, R182, R189: 49.9; R_0603_1608Metric
R26, R29, R52, R55, R78, R81, R105, R108, R131, R134, R158, R161, R185, R188: 5K1; R_0603_1608Metric
R39, R65, R91, R118, R144, R171, R198, R221, R305, R320: 4M7; R_1206_3216Metric
R40, R41, R66, R67, R92, R93, R119, R120, R145, R146, R172, R173, R199, R200: 100; R_0805_2012Metric
R98, R201, R202, R203, R204, R205, R206, R219, R220, R230, R239, R248, R257, R266, R277, R286, R291, R319: 10K; R_0603_1608Metric
R222, R223, R312: 3K3; R_0603_1608Metric
R224, R233, R242, R251, R260, R271, R280: 0R24; R_1206_3216Metric
R225, R234, R243, R252, R261, R272, R281: 50K; R_0603_1608Metric
R226, R235, R244, R253, R262, R273, R282: 20; R_1206_3216Metric
R227, R236, R245, R254, R263, R274, R283: 50; R_1206_3216Metric
R228, R237, R246, R255, R264, R275, R284: 5K; R_0603_1608Metric
R229, R231, R238, R240, R247, R249, R256, R258, R265, R267, R276, R278, R285, R287: 5; R_1206_3216Metric
R232, R241, R250, R259, R268, R279, R288: 0R062; R_1206_3216Metric
R269, R289: 24K3; R_0603_1608Metric
R270, R290: 49K9; R_0805_2012Metric
R292, R296: 27; R_0603_1608Metric
R293, R294, R295, R297, R298, R299, R300, R301, R302, R303, R304, R306, R307, R309, R310, R311: 330; R_0603_1608Metric
R314, R315, R316: 1R0; R_0805_2012Metric
R318: 3K; R_0603_1608Metric
RV1: MOV-10D390K; RV_Disc_D12mm_W3.9mm_P7.5mm
SW1, SW2: USB_PGM; SW_Push_1P1T_NO_CK_KSC6xxJ
U1, U2: SJA1105Q; LFBGA_12x12mm_P0.8mm
U3, U4, U13: SC4626C; SOT-23-5
U5, U6, U7, U8, U9, U10, U11: ADIN1100; LFCSP-40_EP_TheramVias
U12: KSZ9131RNX; VQFN-48-1EP_7x7mm_P0.5mm_EP5.15x5.15mm_ThermalVias
U14, U15: LTC4296-1; QFN-48-1EP_7x7mm_P0.5mm_EP5.3x5.3mm_ThermalVias
U16: RP2040; QFN-56-1EP_7x7mm_P0.4mm_EP3.2x3.2mm
U17: IS25LP128F-JBLE; SOIC-8_5.23x5.23mm_P1.27mm
U18: LM22678TJ-ADJ; TO-263-7_TabPin8
X1: ASE-25.000MHz; Oscillator_SMD_Abracon_ASE-4Pin_3.2x2.5mm
Y1: 12MHz; Crystal_SMD_Abracon_ABM8G-4Pin_3.2x2.5mm

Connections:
25MHz_REFCLK: R14.1, U12.46 (XI)
+3V3: C1.1, C4.1, C7.1, C87.1, C101.1, C115.1, C129.1, C143.1, C157.1, C171.1, C185.1, C187.1, C188.1, C189.1, C229.1, C230.1, C231.1, C232.1, C233.1, C234.1, C235.1, C236.1, C239.1, D1.2 (A), D2.2 (A), D6.2 (A), D7.2 (A), D11.2 (A), D12.2 (A), D16.2 (A), D17.2 (A), D21.2 (A), D22.2 (A), D26.2 (A), D27.2 (A), D31.2 (A), D32.2 (A), D37.1 (K), D40.1 (K), D43.1 (K), D46.1 (K), D49.1 (K), D52.1 (K), D55.1 (K), FB1.1, FB2.1, FB3.2, FB4.2, FB9.2, FB10.2, FB11.2, FB12.2, FB13.2, FB14.2, FB15.2, FB18.2, J1.1 (VTref), J9.14 (LED2+), J9.16 (LED1+), J12.1 (VTref), L25.2, R21.2, R46.2, R47.2, R72.2, R73.2, R98.2, R99.2, R100.2, R125.2, R126.2, R151.2, R152.2, R153.2, R178.2, R179.2, R180.2, R201.1, R202.1, R203.1, R204.1, R205.1, R206.1, R222.1, R223.1, R225.2, R234.2, R243.2, R252.2, R261.2, R272.2, R281.2, R291.1, R314.1, R315.1, R316.1, R317.1, U5.35 (VDDIO), U6.35 (VDDIO), U7.35 (VDDIO), U8.35 (VDDIO), U9.35 (VDDIO), U10.35 (VDDIO), U11.35 (VDDIO), U12.16 (DVDDH), U12.34 (DVDDH), U12.40 (DVDDH), U13.1 (VIN), U16.1 (IOVDD), U16.10 (IOVDD), U16.22 (IOVDD), U16.33 (IOVDD), U16.42 (IOVDD), U16.43 (ADC_AVDD), U16.44 (VREG_IN), U16.48 (USB_VDD), U16.49 (IOVDD), U17.8 (VCC), X1.1 (EN), X1.4 (Vdd)
+24V: C212.1, C223.1, C243.1, D58.1 (K), L27.1, Q45.4 (S), R224.1, R233.1, R242.1, R251.1, R260.1, R271.1, R280.1, U14.4 (HSNSP0), U14.6 (IN), U14.36 (HSNSP4), U14.40 (HSNSP3), U14.44 (HSNSP2), U14.48 (HSNSP1), U15.4 (HSNSP0), U15.6 (IN), U15.48 (HSNSP1)
/100Base-TX-PHY7/1V2: C180.1, C181.1, C182.1, C183.1, C184.1, C186.1, FB16.2, FB17.2, L24.1, U12.18 (DVDDL), U12.23 (DVDDL), U12.26 (DVDDL), U12.30 (DVDDL), U12.39 (DVDDL), U13.4 (VOUT)
/SJA1105Q Power/1V2_A: C6.1, C10.1, C11.1, C12.1, C13.1, C14.1, C15.1, C16.1, C17.1, C26.1, C50.1, FB5.1, FB7.1, L1.1, U1.D6 (VDD_CORE), U1.D9 (VDD_CORE), U1.F4 (VDD_CORE), U1.F11 (VDD_CORE), U1.J4 (VDD_CORE), U1.J11 (VDD_CORE), U1.L6 (VDD_CORE), U1.L9 (VDD_CORE), U3.4 (VOUT)
/SJA1105Q Power/1V2_B: C9.1, C18.1, C19.1, C20.1, C21.1, C22.1, C23.1, C24.1, C25.1, C38.1, C62.1, FB6.1, FB8.1, L2.1, U2.D6 (VDD_CORE), U2.D9 (VDD_CORE), U2.F4 (VDD_CORE), U2.F11 (VDD_CORE), U2.J4 (VDD_CORE), U2.J11 (VDD_CORE), U2.L6 (VDD_CORE), U2.L9 (VDD_CORE), U4.4 (VOUT)
/System Controller/CON_USB+: J11.3 (D+), R292.1
/System Controller/CON_USB-: J11.2 (D-), R296.1
/System Controller/RP_USB+: R292.2, U16.47 (USB_DP)
/System Controller/RP_USB-: R296.2, U16.46 (USB_DM)
/System Controller/SCLK: U16.52 (QSPI_SCLK), U17.6 (CLK)
/System Controller/SD0: U16.53 (QSPI_SD0), U17.5 (DI(IO0))
/System Controller/SD1: U16.55 (QSPI_SD1), U17.2 (DO(IO1))
/System Controller/SD2: U16.54 (QSPI_SD2), U17.3 (IO2)
/System Controller/SD3: U16.51 (QSPI_SD3), U17.7 (IO3)
/System Controller/SS: R312.1, U16.56 (QSPI_SS), U17.1 (~CS)
/System Controller/UART0_RXD: J10.2, U16.3 (GPIO1)
/System Controller/UART0_TXD: J10.1, U16.2 (GPIO0)
/System Controller/nRST: C237.1, J12.10 (~RESET), R291.2, SW1.2, U16.26 (RUN)
GLOBAL_RESET: R300.2, U1.P3 (RST_N), U2.P3 (RST_N), U5.5 (RESET_N), U6.5 (RESET_N), U7.5 (RESET_N), U8.5 (RESET_N), U9.5 (RESET_N), U10.5 (RESET_N), U11.5 (RESET_N), U12.42 (RESET_N)
GND: C1.2, C4.2, C5.2, C6.2, C7.2, C8.2, C9.2, C10.2, C11.2, C12.2, C13.2, C14.2, C15.2, C16.2, C17.2, C18.2, C19.2, C20.2, C21.2, C22.2, C23.2, C24.2, C25.2, C26.2, C27.2, C28.2, C29.2, C30.2, C31.2, C32.2, C33.2, C34.2, C35.2, C36.2, C37.2, C38.2, C39.2, C40.2, C41.2, C42.2, C43.2, C44.2, C45.2, C46.2, C47.2, C48.2, C49.2, C50.2, C51.2, C52.2, C53.2, C54.2, C55.2, C56.2, C57.2, C58.2, C59.2, C60.2, C61.2, C62.2, C63.2, C64.2, C65.2, C66.2, C67.2, C68.2, C69.2, C70.2, C71.2, C72.2, C73.2, C80.2, C81.2, C82.2, C83.2, C84.2, C85.2, C86.2, C87.2, C94.2, C95.2, C96.2, C97.2, C98.2, C99.2, C100.2, C101.2, C108.2, C109.2, C110.2, C111.2, C112.2, C113.2, C114.2, C115.2, C122.2, C123.2, C124.2, C125.2, C126.2, C127.2, C128.2, C129.2, C136.2, C137.2, C138.2, C139.2, C140.2, C141.2, C142.2, C143.2, C150.2, C151.2, C152.2, C153.2, C154.2, C155.2, C156.2, C157.2, C164.2, C165.2, C166.2, C167.2, C168.2, C169.2, C170.2, C171.2, C172.1, C173.1, C174.1, C175.1, C176.2, C177.2, C178.2, C179.2, C180.2, C181.2, C182.2, C183.2, C184.2, C185.2, C186.2, C187.2, C188.2, C189.2, C190.2, C191.2, C213.1, C214.1, C224.1, C225.1, C226.2, C227.2, C228.2, C229.2, C230.2, C231.2, C232.2, C233.2, C234.2, C235.2, C236.2, C237.2, C238.2, C239.2, C240.2, C241.2, C248.2, C249.2, C250.2, C251.2, C252.2, C254.2, C255.2, C256.2, C258.2, C260.2, C262.2, C264.2, C266.2, C268.2, C270.2, D4.1 (A1), D5.1 (A1), D9.1 (A1), D10.1 (A1), D14.1 (A1), D15.1 (A1), D19.1 (A1), D20.1 (A1), D24.1 (A1), D25.1 (A1), D29.1 (A1), D30.1 (A1), D34.1 (A1), D35.1 (A1), D36.2 (A), D39.2 (A), D42.2 (A), D45.2 (A), D48.2 (A), D51.2 (A), D54.2 (A), D57.1 (K), D59.2 (A), J1.3 (GND), J1.5 (GND), J1.9 (GNDDetect), J10.3, J11.5 (GND), J12.3 (GND), J12.5 (GND), J12.9 (GNDDetect), L28.4, Q3.2 (E), Q9.2 (E), Q15.2 (E), Q21.2 (E), Q27.2 (E), Q31.1 (S), Q31.2 (S), Q31.3 (S), Q34.2 (E), Q40.2 (E), Q44.1 (S), Q44.2 (S), Q44.3 (S), R13.1, R16.1, R39.2, R40.1, R41.1, R65.2, R66.1, R67.1, R91.2, R92.1, R93.1, R118.2, R119.1, R120.1, R144.2, R145.1, R146.1, R171.2, R172.1, R173.1, R198.2, R199.1, R200.1, R219.2, R220.2, R221.2, R229.2, R238.2, R247.2, R256.2, R265.2, R269.2, R270.1, R276.2, R285.2, R289.2, R290.1, R305.2, R318.2, R319.2, R320.2, SW1.1, SW2.1, U1.A1 (VSS), U1.A14 (VSS), U1.B13 (VSS), U1.E5 (VSS), U1.E6 (VSS), U1.E7 (VSS), U1.E8 (VSS), U1.E9 (VSS), U1.E10 (VSS), U1.F5 (VSS), U1.F6 (VSS), U1.F7 (VSS), U1.F8 (VSS), U1.F9 (VSS), U1.F10 (VSS), U1.G5 (VSS), U1.G6 (VSS), U1.G7 (VSS), U1.G8 (VSS), U1.G9 (VSS), U1.G10 (VSS), U1.H5 (VSS), U1.H6 (VSS), U1.H7 (VSS), U1.H8 (VSS), U1.H9 (VSS), U1.H10 (VSS), U1.J2 (VSSA_PLL), U1.J5 (VSS), U1.J6 (VSS), U1.J7 (VSS), U1.J8 (VSS), U1.J9 (VSS), U1.J10 (VSS), U1.K4 (VSS), U1.K5 (VSS), U1.K6 (VSS), U1.K7 (VSS), U1.K8 (VSS), U1.K9 (VSS), U1.K10 (VSS), U1.L2 (VSSA_OSC), U1.L4 (i.c.), U1.L7 (VSS), U1.N2 (VSS), U1.N13 (VSS), U1.P1 (VSS), U1.P14 (VSS), U2.A1 (VSS), U2.A14 (VSS), U2.B13 (VSS), U2.E5 (VSS), U2.E6 (VSS), U2.E7 (VSS), U2.E8 (VSS), U2.E9 (VSS), U2.E10 (VSS), U2.F5 (VSS), U2.F6 (VSS), U2.F7 (VSS), U2.F8 (VSS), U2.F9 (VSS), U2.F10 (VSS), U2.G5 (VSS), U2.G6 (VSS), U2.G7 (VSS), U2.G8 (VSS), U2.G9 (VSS), U2.G10 (VSS), U2.H5 (VSS), U2.H6 (VSS), U2.H7 (VSS), U2.H8 (VSS), U2.H9 (VSS), U2.H10 (VSS), U2.J2 (VSSA_PLL), U2.J5 (VSS), U2.J6 (VSS), U2.J7 (VSS), U2.J8 (VSS), U2.J9 (VSS), U2.J10 (VSS), U2.K4 (VSS), U2.K5 (VSS), U2.K6 (VSS), U2.K7 (VSS), U2.K8 (VSS), U2.K9 (VSS), U2.K10 (VSS), U2.L2 (VSSA_OSC), U2.L4 (i.c.), U2.L7 (VSS), U2.N2 (VSS), U2.N13 (VSS), U2.P1 (VSS), U2.P14 (VSS), U3.2 (GND), U4.2 (GND), U5.41 (EP), U6.41 (EP), U7.41 (EP), U8.41 (EP), U9.41 (EP), U10.41 (EP), U11.41 (EP), U12.29 (VSS), U12.49 (EP), U13.2 (GND), U14.21 (GND), U14.24 (LSRC), U14.49 (GND), U15.21 (GND), U15.24 (LSRC), U15.49 (GND), U16.19 (TESTEN), U16.57 (GND), U17.4 (GND), U18.4 (GND), U18.8 (GND), X1.2 (GND), Y1.1, Y1.3
GNDPWR: C80.1, C94.1, C108.1, C122.1, C136.1, C150.1, C164.1, C176.1, C240.1, C256.1, H1.1, H2.1, H3.1, H4.1, H5.1, H6.1, H7.1, H8.1, H9.1, H10.1, J2.3, J3.3, J4.3, J5.3, J6.3, J7.3, J8.3, J9.SH, J11.6 (Shield), R39.1, R65.1, R91.1, R118.1, R144.1, R171.1, R198.1, R221.1, R305.1, R320.1
I2C_SCK: R222.2, R302.2, U5.27 (MDC), U6.27 (MDC), U7.27 (MDC), U8.27 (MDC), U9.27 (MDC), U10.27 (MDC), U11.27 (MDC), U12.36 (MDC)
I2C_SDA: R223.2, U5.26 (MDIO), U6.26 (MDIO), U7.26 (MDIO), U8.26 (MDIO), U9.26 (MDIO), U10.26 (MDIO), U11.26 (MDIO), U12.37 (MDIO), U16.15 (GPIO12)
MDI_PoDL_N_0: L3.2, Q6.2 (E), R227.2, R231.2, R232.2, U14.25 (OUTM0)
MDI_PoDL_N_1: L6.2, Q12.2 (E), R236.2, R240.2, R241.2, U14.27 (OUTM1)
MDI_PoDL_N_2: L9.2, Q18.2 (E), R245.2, R249.2, R250.2, U14.29 (OUTM2)
MDI_PoDL_N_3: L12.2, Q24.2 (E), R254.2, R258.2, R259.2, U14.30 (OUTM3)
MDI_PoDL_N_4: L15.2, Q30.2 (E), R263.2, R267.2, R268.2, U14.32 (OUTM4)
MDI_PoDL_N_5: L18.2, Q37.2 (E), R274.2, R278.2, R279.2, U15.25 (OUTM0)
MDI_PoDL_N_6: L21.2, Q43.2 (E), R283.2, R287.2, R288.2, U15.27 (OUTM1)
MDI_PoDL_P_0: C192.1, C193.1, C194.1, D36.1 (K), L3.3, Q1.3 (D), Q2.3 (C), Q4.2 (S), U14.1 (OUTP0)
MDI_PoDL_P_1: C196.1, C197.1, C198.1, D39.1 (K), L6.3, Q7.3 (D), Q8.3 (C), Q10.2 (S), U14.45 (OUTP1)
MDI_PoDL_P_2: C200.1, C201.1, C202.1, D42.1 (K), L9.3, Q13.3 (D), Q14.3 (C), Q16.2 (S), U14.41 (OUTP2)
MDI_PoDL_P_3: C204.1, C205.1, C206.1, D45.1 (K), L12.3, Q19.3 (D), Q20.3 (C), Q22.2 (S), U14.37 (OUTP3)
MDI_PoDL_P_4: C208.1, C209.1, C210.1, D48.1 (K), L15.3, Q25.3 (D), Q26.3 (C), Q28.2 (S), U14.33 (OUTP4)
MDI_PoDL_P_5: C215.1, C216.1, C217.1, D51.1 (K), L18.3, Q32.3 (D), Q33.3 (C), Q35.2 (S), U15.1 (OUTP0)
MDI_PoDL_P_6: C219.1, C220.1, C221.1, D54.1 (K), L21.3, Q38.3 (D), Q39.3 (C), Q41.2 (S), U15.45 (OUTP1)
MDI_SSCPI_0: Q2.2 (E), U16.13 (GPIO10)
MDI_SSCPI_1: Q8.2 (E), U16.17 (GPIO14)
MDI_SSCPI_2: Q14.2 (E), U16.27 (GPIO16)
MDI_SSCPI_3: Q20.2 (E), U16.29 (GPIO18)
MDI_SSCPI_4: Q26.2 (E), U16.31 (GPIO20)
MDI_SSCPI_5: Q33.2 (E), U16.34 (GPIO22)
MDI_SSCPI_6: Q39.2 (E), U16.36 (GPIO24)
MDI_SSCPO_0: R228.1, R301.2
MDI_SSCPO_1: R237.1, R303.2
MDI_SSCPO_2: R246.1, R304.2
MDI_SSCPO_3: R255.1, R306.2
MDI_SSCPO_4: R264.1, R307.2
MDI_SSCPO_5: R275.1, R309.2
MDI_SSCPO_6: R284.1, R310.2
unnamed: C2.1, R12.2, R13.2
unnamed: C2.2, U1.K2 (OSC_IN)
unnamed: C3.1, R15.2, R16.2
unnamed: C3.2, U2.K2 (OSC_IN)
unnamed: C5.1, FB1.2, U3.1 (VIN)
unnamed: C8.1, FB2.2, U4.1 (VIN)
unnamed: C27.1, C28.1, FB5.2, U1.J1 (VDDA_PLL)
unnamed: C29.1, C30.1, C31.1, C32.1, C33.1, C34.1, C35.1, C36.1, C37.1, C53.1, C54.1, C55.1, C56.1, C57.1, C58.1, C59.1, C60.1, C61.1, FB3.1, U1.D4 (VDDIO_MII0), U1.D5 (VDDIO_MII1), U1.D7 (VDDIO_MII1), U1.D8 (VDDIO_MII1), U1.D10 (VDDIO_MII2), U1.D11 (VDDIO_MII2), U1.E4 (VDDIO_MII0), U1.E11 (VDDIO_MII2), U1.G4 (VDDIO_MII0), U1.G11 (VDDIO_MII3), U1.H4 (VDDIO_CLO), U1.H11 (VDDIO_MII3), U1.K11 (VDDIO_MII3), U1.L5 (VDDIO_HOST), U1.L8 (VDDIO_MII4), U1.L10 (VDDIO_MII4), U1.L11 (VDDIO_MII4)
unnamed: C39.1, C40.1, FB6.2, U2.J1 (VDDA_PLL)
unnamed: C41.1, C42.1, C43.1, C44.1, C45.1, C46.1, C47.1, C48.1, C49.1, C65.1, C66.1, C67.1, C68.1, C69.1, C70.1, C71.1, C72.1, C73.1, FB4.1, U2.D4 (VDDIO_MII0), U2.D5 (VDDIO_MII1), U2.D7 (VDDIO_MII1), U2.D8 (VDDIO_MII1), U2.D10 (VDDIO_MII2), U2.D11 (VDDIO_MII2), U2.E4 (VDDIO_MII0), U2.E11 (VDDIO_MII2), U2.G4 (VDDIO_MII0), U2.G11 (VDDIO_MII3), U2.H4 (VDDIO_CLO), U2.H11 (VDDIO_MII3), U2.K11 (VDDIO_MII3), U2.L5 (VDDIO_HOST), U2.L8 (VDDIO_MII4), U2.L10 (VDDIO_MII4), U2.L11 (VDDIO_MII4)
unnamed: C51.1, C52.1, FB7.2, U1.K1 (VDDA_OSC)
unnamed: C63.1, C64.1, FB8.2, U2.K1 (VDDA_OSC)
unnamed: C74.1, D5.2 (A2), R17.1, R23.2, R26.2
unnamed: C74.2, L4.2, R17.2
unnamed: C75.1, L4.1, R18.1
unnamed: C75.2, L5.1, R18.2
unnamed: C76.1, D4.2 (A2), R29.2, R30.2, R34.1
unnamed: C76.2, L4.3, R34.2
unnamed: C77.1, L4.4, R35.1
unnamed: C77.2, L5.2, R35.2
unnamed: C78.1, D3.1 (A1), J2.2, L3.1, L5.4
unnamed: C78.2, R40.2
unnamed: C79.1, D3.2 (A2), J2.1, L3.4, L5.3
unnamed: C79.2, R41.2
unnamed: C81.1, U5.23 (DLDO_1P1), U5.24 (DVDD_1P1)
unnamed: C82.1, U5.20 (CEXT_3)
unnamed: C83.1, U5.19 (CEXT_2)
unnamed: C84.1, C85.1, C86.1, FB9.1, U5.16 (AVDD_H), U5.17 (AVDD_H), U5.22 (AVDD_L)
unnamed: C88.1, D10.2 (A2), R42.1, R49.2, R52.2
unnamed: C88.2, L7.2, R42.2
unnamed: C89.1, L7.1, R43.1
unnamed: C89.2, L8.1, R43.2
unnamed: C90.1, D9.2 (A2), R55.2, R56.2, R60.1
unnamed: C90.2, L7.3, R60.2
unnamed: C91.1, L7.4, R61.1
unnamed: C91.2, L8.2, R61.2
unnamed: C92.1, D8.1 (A1), J3.2, L6.1, L8.4
unnamed: C92.2, R66.2
unnamed: C93.1, D8.2 (A2), J3.1, L6.4, L8.3
unnamed: C93.2, R67.2
unnamed: C95.1, U6.23 (DLDO_1P1), U6.24 (DVDD_1P1)
unnamed: C96.1, U6.20 (CEXT_3)
unnamed: C97.1, U6.19 (CEXT_2)
unnamed: C98.1, C99.1, C100.1, FB10.1, U6.16 (AVDD_H), U6.17 (AVDD_H), U6.22 (AVDD_L)
unnamed: C102.1, D15.2 (A2), R68.1, R75.2, R78.2
unnamed: C102.2, L10.2, R68.2
unnamed: C103.1, L10.1, R69.1
unnamed: C103.2, L11.1, R69.2
unnamed: C104.1, D14.2 (A2), R81.2, R82.2, R86.1
unnamed: C104.2, L10.3, R86.2
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

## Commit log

2023-04-10 Initial Schematic Commit
    [100Base-TX-PHY7.kicad_sch, 10Base-T1L-PHY1.kicad_sch, 10Base-T1L-PHY2.kicad_sch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]
2023-04-10 Update Schematic Name
    [Open_10Base-T1L_Switch.kicad_sch, PoDL_REG1.kicad_sch]
2023-04-10 Removing Deleted Sheets
    [10Base-T1S_PHY0.kicad_sch, PoDL_PHY0-4.kicad_sch, PoDL_REG0.kicad_sch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]
2023-04-10 Renaming Sheets
    [10Base-T1L-PHY0.kicad_sch, Open_10Base-T1L_Switch.kicad_sch, PoDL_PHY0-1.kicad_sch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]
2023-04-10 Minor corrections
    [100Base-TX-PHY7.kicad_sch, 10Base-T1L-PHY0.kicad_sch, 10Base-T1L-PHY1.kicad_sch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]
2023-04-10 Assigning Footprints
    [100Base-TX-PHY7.kicad_sch, 10Base-T1L-PHY0.kicad_sch, 10Base-T1L-PHY1.kicad_sch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]
2023-04-10 Pinout Correction for LTC4296 and cleanup
    [100Base-TX-PHY7.kicad_sch, 10Base-T1L-PHY0.kicad_sch, 10Base-T1L-PHY1.kicad_sch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]
2023-04-10 New Schematic
2023-04-10 New Schematic PDF
2023-04-10 Fixing termination for T1L PHYs
    [10Base-T1L-PHY0.kicad_sch, 10Base-T1L-PHY1.kicad_sch, 10Base-T1L-PHY2.kicad_sch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]
2023-04-11 Update Schematic PDF
2023-04-12 Correcting SCCP spelling
    [PoDL_PHY0-1.kicad_sch, PoDL_PHY2-3.kicad_sch, PoDL_PHY4_REG0.kicad_sch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]
2023-04-12 Restructuring Repo
    [100Base-TX-PHY7.kicad_sch, 10Base-T1L-PHY0.kicad_sch, 10Base-T1L-PHY1.kicad_sch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]
2023-04-17 Initial Placement and Hierarchical Schematic
    [100Base-TX-PHY7.kicad_sch, 10Base-T1L-PHY.kicad_sch, 10Base-T1L-PHY0.kicad_sch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]
2023-04-17 Removing unused files
    [10Base-T1L-PHY0.kicad_sch, 10Base-T1L-PHY1.kicad_sch, 10Base-T1L-PHY2.kicad_sch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]
2023-04-18 Smaller Cicruit Corrections
    [100Base-TX-PHY7.kicad_sch, Open_10Base-T1L_Switch.kicad_sch, System_Controller.kicad_sch]
2023-04-18 Updating Schematic PDF and Placement Images

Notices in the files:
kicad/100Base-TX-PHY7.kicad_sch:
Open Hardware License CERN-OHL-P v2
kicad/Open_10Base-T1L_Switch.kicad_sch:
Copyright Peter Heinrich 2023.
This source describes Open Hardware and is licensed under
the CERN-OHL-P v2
